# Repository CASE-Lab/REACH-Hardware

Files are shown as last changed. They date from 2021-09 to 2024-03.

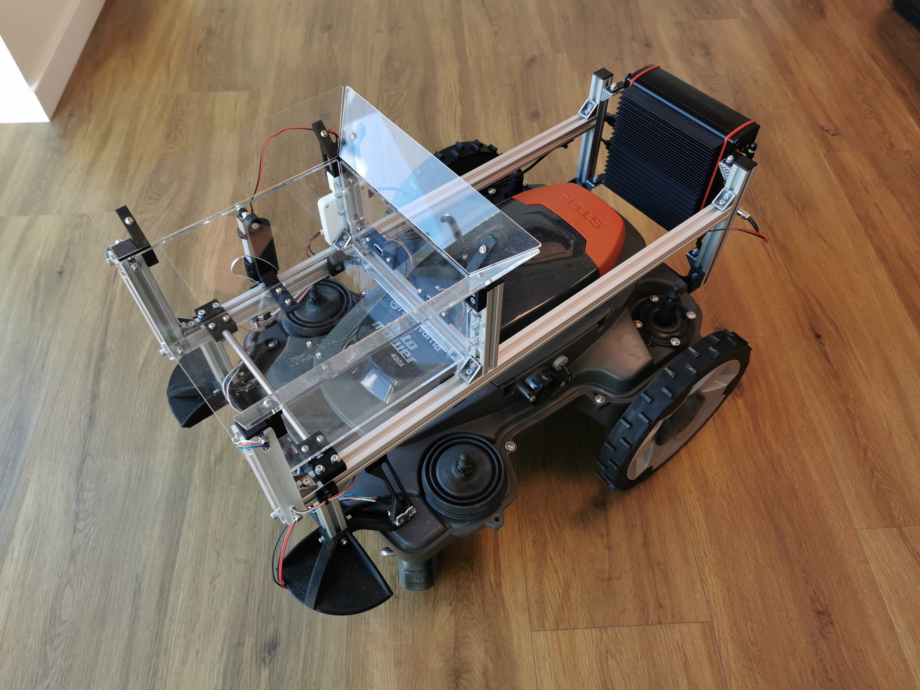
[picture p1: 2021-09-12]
Images/HRP/HRP_WithGarbageMoverAndREACH.jpg

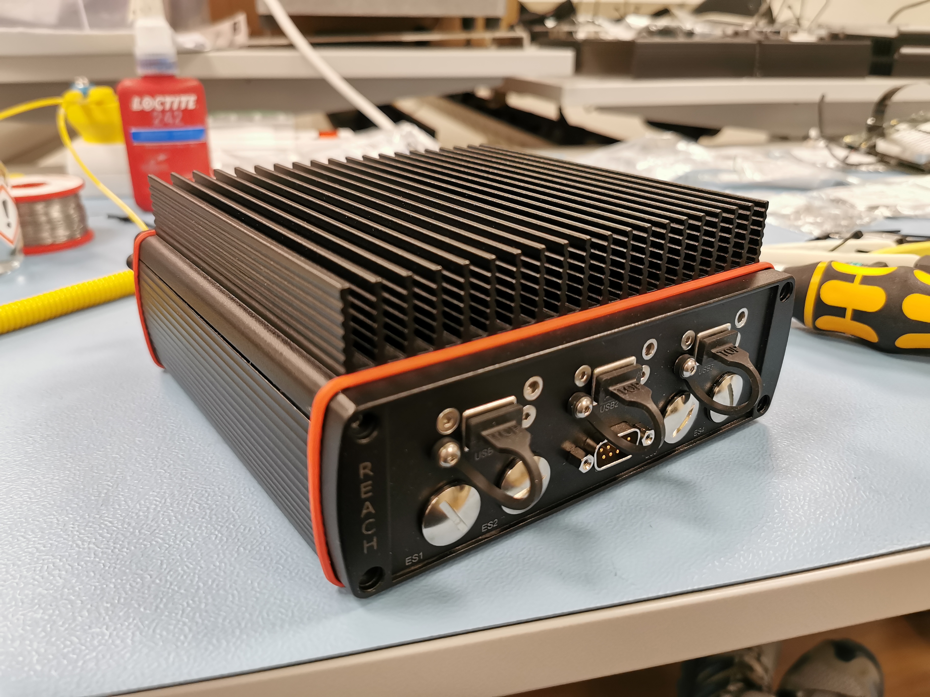
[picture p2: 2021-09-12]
Images/StandardVersion/TopStandardVersion.jpg

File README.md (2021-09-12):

# REACH-Hardware
REACH - Rugged Extensible Autonomous Control Hardware

## The REACH Unit
Is a fairly compact linux computer built upon the Nvidia Xavier NX developer kit. The main idea is to make the developer kit rugged and modular/extensible. 

### Fields of Interest
The unit is supposed to be used in the fields of robotics and automation if more robust and/or modular solution is needed. 

Example: A REACH unit is used in a research project with an autonomous jet ski. The rugged enclosure makes it ideal for the harsh environment. Because of it's modularity it also allows for future extensions to meet new needs that can arise. This version of the unit features two camera inputs and telemetry support.

Example: A REACH unit is used for controlling a Husqvarna Research Platform (HRP) (a modified robotic lawn mower for research purposes). It allows for enough computational power to easily run ROS2, while also allowing for a camera and USB devices to be connected in the future. This version of the unit is the standard version with one camera input and GPIO ports.

### Features
* Built upon an Nvidia NX developer kit
* Passively cooled
* Should attain an IP65 rating (untested)
* Allows for use of up to two Raspberry PI cameras over a distance of up to 10m using the HDMI to CSI adapter (adapter found in REACH-Extensions). (Number of supported cameras varies depending on the configuration)
* All standard connectors from the dev kit have been routed to the outside of the enclosure (1x Ethernet port, Wifi, 2-3x USB ports)
* Features up to 4 expansion cards which can add function such as CAN and RS232 support. Each card can be conencted to a standard M12 industrial connector located on the front panel.
* Depending on the configuration the unit features either 2 analogue and 5 digital GPIO pins or telemetry support.

[TOC]

## Getting Started

### Flashing with Nvidia SDK

* Currently requires Ubuntu 18.04 for Nvidia SDK Manager
* Can also be used on newer Ubuntu versions via Docker. [Instructions](https://docs.nvidia.com/sdk-manager/docker-containers/index.html)

### Booting from NVME SSD

* [Jetsonhacks Guide](https://www.jetsonhacks.com/2020/05/29/jetson-xavier-nx-run-from-ssd/)

### Stress testing

* Monitoring using jtop (requires pip for installation)

  ```sh
  # install
  sudo -H pip install -U jetson-stats
  # run
  sudo jtop
  ```

* Stress test GPU (and also CPU indirectly by running multiple instances of glmark2)

  ```sh
  # install
  sudo apt-get install -y glmark2
  # run
  glmark2
  ```

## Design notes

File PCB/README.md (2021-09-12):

# REACH-Hardware-PCB
This project uses only the KiCad ECAD program.

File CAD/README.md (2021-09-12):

REACH-Hardware-CAD
Contains the mechanical design files for the REACH unit. 

There are three assemblies of the unit that has been exported as .step. The others requires Autodesk Inventor 2022 or later.
- REACH_cam_version: Two camera inputs, two USB and GPIOs
- REACH_standard_version: One camera input, three USB and GPIOs
- REACH_waverunner_version: Two camera inputs, two USB and Telemetry support (used for the autonomousjet ski, MARV system)

The Inventor projets contains every part required to make the three exported versions, the unused parts are just hidden.

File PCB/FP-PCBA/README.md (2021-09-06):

# FP-PCBA

Front Panel PCB Assembly

* Breaks out USB 3.0 from Jetson development board to front panel
* Holds 4 modular expansion headers

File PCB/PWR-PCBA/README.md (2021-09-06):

# PWR-PCBA

Power distribution PCB assembly

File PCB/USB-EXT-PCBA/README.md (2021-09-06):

# USB-EXT-PCBA

USB interconnection to bring down upper USB connections to

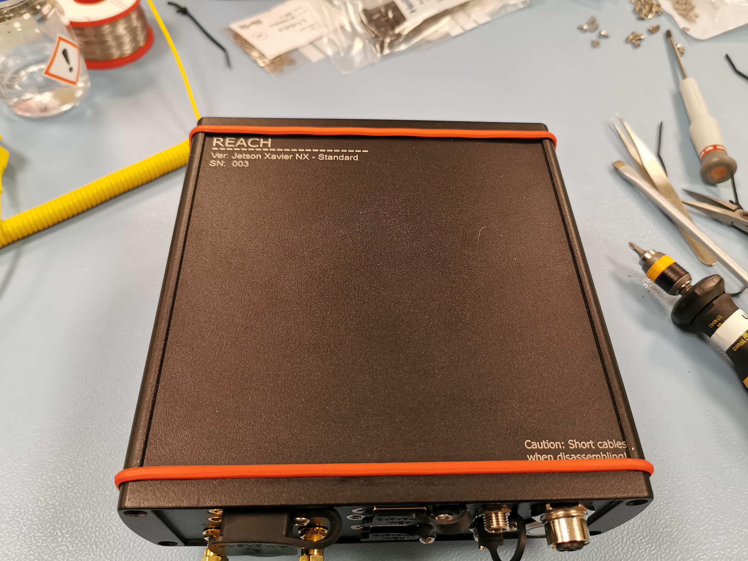
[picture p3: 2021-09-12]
Images/StandardVersion/BottomStandardVersion.jpg

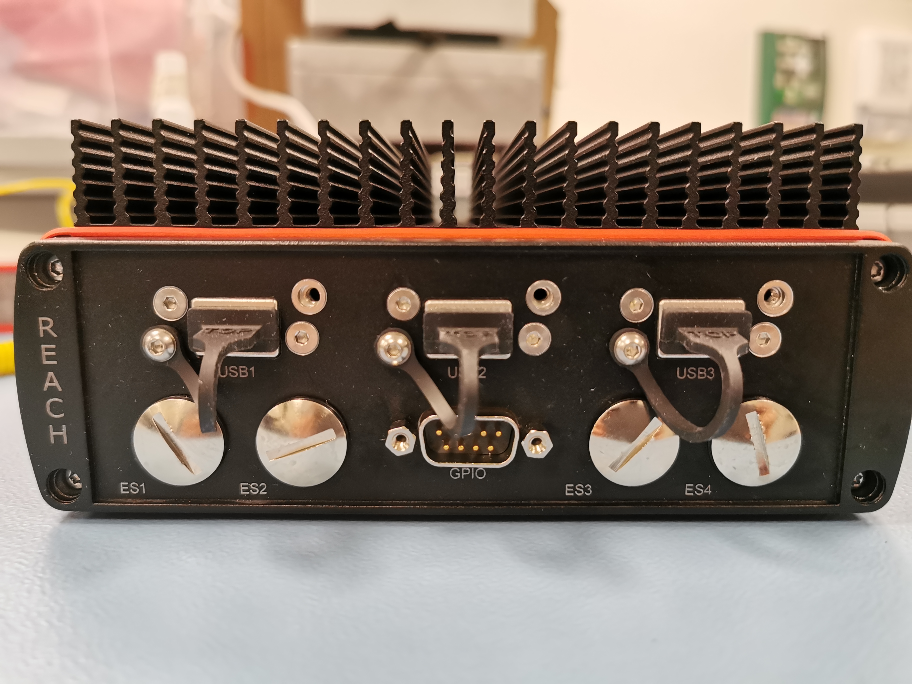
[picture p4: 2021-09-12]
Images/StandardVersion/FrontPanelStandardVersion.jpg

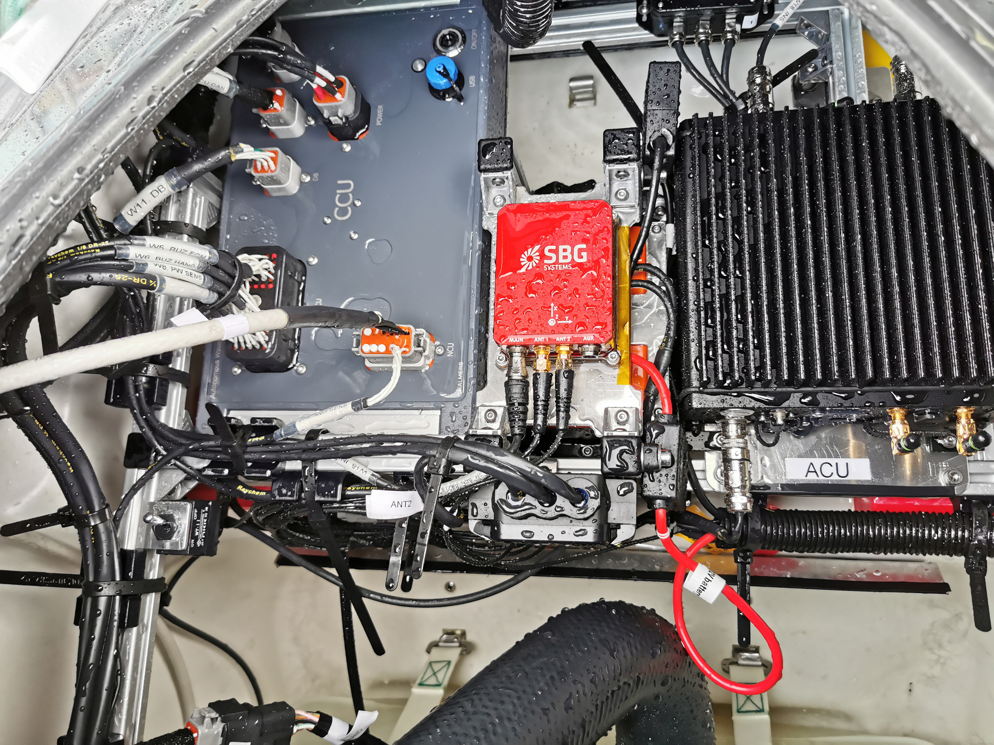
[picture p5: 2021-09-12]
Images/AutonomousJetSki/REACH_Unit_InJetSkiFrontCompartment.jpg

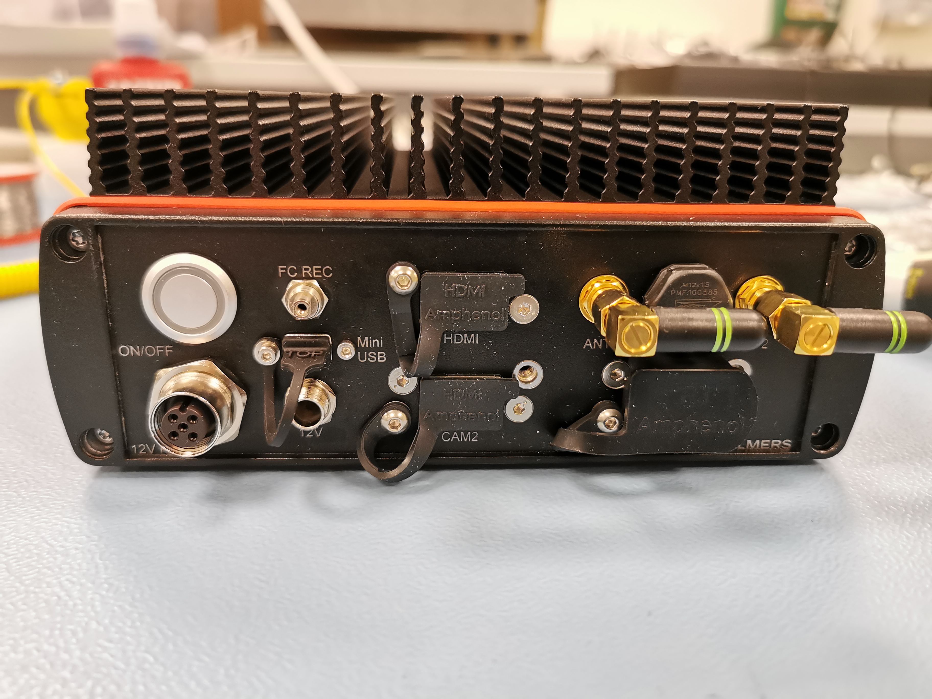
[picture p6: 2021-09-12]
Images/StandardVersion/BackPanelStandardVersion.jpg

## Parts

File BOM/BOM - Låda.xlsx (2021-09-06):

Komponent | Qty | Orderkod | Länk | Alt Länk | Tillverkare och MPN | Kommentar
Inbyggnadslåda
Låda - ABPH 1600-0150 K | 1 | 83658532 | https://se.lappgroup.com/produkter/webshop/kapslingar-och-skaap/elektronikkapslingar-i-metall/alubos-elegant-kapsling-av-aluminium-med-hoeg-skyddsklass-ip65/a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 |  | Bopla - ABPH 1600-0150 K
Gavel - ABD 1600 | 2 | 83654370 | https://se.lappgroup.com/produkter/webshop/kapslingar-och-skaap/elektronikkapslingar-i-metall/alubos-elegant-kapsling-av-aluminium-med-hoeg-skyddsklass-ip65/a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 |  | Bopla - ABD 1600
Packning - DI 1600-5002 elr DI 1600-3000 | 1 | 83654303 | https://se.lappgroup.com/produkter/webshop/kapslingar-och-skaap/elektronikkapslingar-i-metall/alubos-elegant-kapsling-av-aluminium-med-hoeg-skyddsklass-ip65/a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 |  | Bopla - DI 1600-5002 | Säljes i 10 pack
Fästen - AB-WL 3 | 1 | 150-79-678 | https://www.elfa.se/sv/vaeggfaeste-stal-svart-bopla-ab-wl/p/15079678 |  | Bopla - AB-WL 3
Bakre panel
On/Off Button - Staus LED
82-4551.1123 - 16mm rund | 1 | 301-27-185 | https://www.elfa.se/sv/tryckknapp-med-belysning-bla-16mm-12v-eao-82-4551-1123/p/30127185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 | https://se.rs-online.com/web/p/push-button-switches/8114053/?searchHistory=%7B%22enabled%22%3Atrue%7D | EAO - 82-4551.1123
Strömkontakter
Barrel - ST10U | 1 | 878-5257 | https://se.rs-online.com/web/p/dc-power-connectors/8785257/?searchHistory=%7B%22enabled%22%3Atrue%7D |  | Switchcraft - ST10U
M12 - 1424134 | 1 | 651-1424134 | https://www.mouser.se/ProductDetail/651-1424134 |  | Phoenix contact - 1424134
Force recovery switch
MB2011SD3G01-CA | 1 | 633-MB2011SD3G01-CA | https://www.mouser.se/ProductDetail/633-MB2011SD3G01-CA |  | NKK - MB2011SD3G01-CA
AT4042H - Boot for recovery switch | 0 |  |  |  | NKK - AT4042H
USB mini
MUSBR-B551-30 | 1 | MUSBR-B551-30-ND | https://www.digikey.se/product-detail/sv/amphenol-icc-commercial-products/MUSBR-B551-30/MUSBR-B551-30-ND/6137591 | https://se.farnell.com/amphenol-commercial-products/musbrb55130/t-t-usb-2-0-typ-mini-b-hona-ip67/dp/2708983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 | Amphenol - MUSBR-B551-30
HDMI kontakt (kamera och skärm utgång)
MHDR-A511-M0 | 2 | 523-MHDR-A511-M0 | https://www.mouser.se/ProductDetail/523-MHDR-A511-M0 |  | Amphenol - MHDR-A511-M0
Gore ventil
Ventil - PMF 100585 | 1 | 300-82-596 | https://www.elfa.se/sv/tryckutjaemningselement-m12-12-2mm-ip69k-polyamid-svart-gore-associates-gmbh-pmf-100585/p/30082596 |  | Gore - PMF 100585
Mutter M12 | 1 | 155-02-455 | https://www.elfa.se/sv/mutter-m12-gra-hummel-262-1200-50/p/15502455?mainId=30082596 |  | Hummel - 1.262.1200.50
Wifi
Antenn | 0 | 741-001-0012 | https://www.mouser.se/ProductDetail/741-001-0012 |  | Laird - 001-0012
Antenn liten | 2 | 960-GW260152 | https://www.mouser.se/ProductDetail/Taoglas/GW260152/?qs=WUa1z%2FNV9%252B3LPhGjmEzKfw%3D%3D |  | Taoglas - GW.26.0152
Koaxialkabel | 2 | 523-095-902-503-150 | https://www.mouser.se/ProductDetail/523-095-902-503-150/ |  | Amphenol - 095-902-503-150 | OSB uppdatera till Amphenol
RJ45 kontakt
MRJ5784M1 | 1 | 523-MRJ5784M1 | https://www.mouser.se/ProductDetail/523-MRJ5784M1 |  | Amphenol - MRJ5784M1
Dust covers
USB mini - MUSB2E151015BP | 1 | 523-MUSB2E151015BP | https://www.mouser.se/ProductDetail/523-MUSB2E151015BP | https://se.farnell.com/amphenol-icc-commercial-products/musb-2e151-015bp/dust-cover-mini-usb-conn-rubber/dp/2751481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 | Amphenol - MUSB2E151015BP
HDMI - MHDR2A11014BP | 2 | 523-MHDR2A11014BP | https://www.mouser.se/ProductDetail/523-MHDR2A11014BP | https://www.digikey.se/product-detail/en/MHDR2A11014BP/MHDR2A11014BP-ND/8572893?curr=usd | Amphenol - MHDR2A11014BP
RJ45 - MRJ-2586-20BP | 0 | 523-MRJ-2586-20BP | https://www.mouser.se/ProductDetail/523-MRJ-2586-20BP |  | Amphenol - MRJ-2586-20BP
RJ45 - MRJ258642BP | 1 | MRJ258642BP-ND | https://www.digikey.se/product-detail/en/MRJ258642BP/MRJ258642BP-ND/4889368?curr=usd | https://se.farnell.com/amphenol-commercial-products/mrj258642bp/dammlock-modul-r-kontakt-gummi/dp/2708972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 | Amphenol - MRJ258642BP
Nitmuttrar/Skruv
PD-CAP-3/8-0 | 4 | 650-PD-CAP-3/8-0 | https://www.mouser.se/ProductDetail/TE-Connectivity-Raychem/PD-CAP-3-8-0/?qs=tWoSwDyEbWQOoOS7Tg0daQ%3D%3D |  | TE Connectivity - PD-CAP-3/8-0
PSZROX-0315 | 0 | 623-5498 | https://se.rs-online.com/web/p/threaded-inserts/6235498/?searchHistory=%7B%22enabled%22%3Atrue%7D |  | POP - PSZROX-0315
M3X9.0 (1.5-1.5) RH-KB ST/ST A4 RIV-NUT | 4 | 206-7808 | https://se.rs-online.com/web/p/rivets/2067808 |  | RS PRO
ISO 4762 - M2 x 6ISO | 1
ISO 4762 - M2 x 8ISO | 1
ISO 10642 - M3x6 | 5
ISO 7380-1 - M3 x 6 | 2
ISO 7380-1 - M3 x 8 | 1
PCBS
Mini USB adapter | 1
HDMI adapter | 1
Camera adapter | 1
Främre panel
USB kontakter
MUSBR-3193-M0 | 3 (2) | 176-9048 | https://se.rs-online.com/web/p/usb-connectors/1769048/?searchHistory=%7B%22enabled%22%3Atrue%7D |  | Amphenol - MUSBR-3193-M0 | Antingen 3 USB och en HDMI för kamera, eller 4 USB
HDMI kontakt (kamera)
MHDR-A511-M0 | 0 (1) | 523-MHDR-A511-M0 | https://www.mouser.se/ProductDetail/523-MHDR-A511-M0 |  | Amphenol - MHDR-A511-M0 | Antingen 3 USB och en HDMI för kamera, eller 4 USB
Extension M12 PG9 kontakter (upp till 4 st)
CAN Bus - T4131012051-000, A-key, 5 pin | 1 | 134-5763 | https://se.rs-online.com/web/p/products/1345763/ |  | TE - T4131012051-000
M12 dust cap (invändig gänga) | - | 571-2823064-1 | https://www.mouser.se/ProductDetail/571-2823064-1 |  | TE - 2823064-1 | En per kontakt
Pluggar PG9 - Oring | - | 175-3751 | https://se.rs-online.com/web/p/cable-gland-plugs/1753751/?sra=pmpn |  | Alpha Wire - HPP9 BK080 | En per tomt hål, för oringen
Pluggar PG9 | - | 243-9191 | https://se.rs-online.com/web/p/cable-gland-plugs/2439191/?sra=pstk |  | Lapp - 52003390
Mutter till Plugg PG9 | - | 161-2979 | https://se.rs-online.com/web/p/cable-gland-locknuts/1612979/?searchHistory=%7B%22enabled%22%3Atrue%7D |  | SES Sterling - ?? | En per tomt hål
DSUB 9 Kontakt
MDBRE09PMAN0 | 1 | 523-MDBRE09PMAN0 | https://www.mouser.se/ProductDetail/523-MDBRE09PMAN0 |  | Amphenol - MDBRE09PMAN0
Standoff - 5207953-3 | 2 | 717-4559 | https://se.rs-online.com/web/p/d-sub-connector-accessories/7174559/?searchHistory=%7B%22enabled%22%3Atrue%7D |  | TE - 5207953-3
Dust covers
HDMI - MHDR2A11014BP | 0 (1) | 523-MHDR2A11014BP | https://www.mouser.se/ProductDetail/523-MHDR2A11014BP | https://www.digikey.se/product-detail/en/MHDR2A11014BP/MHDR2A11014BP-ND/8572893?curr=usd | Amphenol - MHDR2A11014BP | Antingen 3 USB och en HDMI för kamera, eller 4 USB
USB A - MUSB-2A111-024-BP | 3 (2) | 523-MUSB2A111024BP | https://www.mouser.se/ProductDetail/523-MUSB2A111024BP |  | Amphenol - MUSB-2A111-024-BP | Antingen 3 USB och en HDMI för kamera, eller 4 USB
DSUB 9 | 1
Nitmuttrar/Skruv
PD-CAP-3/8-0 | 6 | 650-PD-CAP-3/8-0 | https://www.mouser.se/ProductDetail/TE-Connectivity-Raychem/PD-CAP-3-8-0/?qs=tWoSwDyEbWQOoOS7Tg0daQ%3D%3D |  | TE Connectivity - PD-CAP-3/8-0
PSZROX-0315 | 0 | 623-5498 | https://se.rs-online.com/web/p/threaded-inserts/6235498/?searchHistory=%7B%22enabled%22%3Atrue%7D |  | POP - PSZROX-0315
M3X9.0 (1.5-1.5) RH-KB ST/ST A4 RIV-NUT | 6 | 206-7808 | https://se.rs-online.com/web/p/rivets/2067808 |  | RS PRO
ISO 10642 - M3x6 | 6
ISO 7380-1 - M3 x 8 | 3
D-sub standoff | 2 | 717-4559 | https://se.rs-online.com/web/p/d-sub-connector-accessories/7174559/ |  | TE Connectivity - 5207953-3
Hårdvara insida/övrigt
Jetson nano- ELLER Jetson NX dev kit
32 gb minneskort, alt även m2 ssd för NX |  |  | https://www.dustin.se/product/5011208877/ultra | https://www.dustin.se/product/5011146123/a2000
Wifi modul (följer med NX)
Modul | 0 | 607-8265.NGWMG.NV | https://www.mouser.se/ProductDetail/Intel/8265NGWMGNV?qs=sGAEpiMZZMu3sxpa5v1qrvoXwgKUd5RfZxSJYigdw1I= |  | Intel - 8265.NGWMG.NV
HDMI kabel och Kontakt
Adafruit 3550 - L böjd HDMI kontakt | 1 | 1528-2364-ND/485-3550 | https://www.digikey.se/product-detail/sv/adafruit-industries-llc/3550/1528-2364-ND/7623052 | https://www.mouser.se/ProductDetail/Adafruit/3550?qs=YCa%2FAAYMW01YtgwxLLaB3Q%3D%3D | Adafruit - 3550
Adafruit 3561 - Flatkabel - 20cm | 1 | 1528-2375-ND/485-3561 | https://www.digikey.se/product-detail/sv/adafruit-industries-llc/3561/1528-2375-ND/7623063 | https://www.mouser.se/ProductDetail/Adafruit/3561?qs=YCa%2FAAYMW0043V1Jh9FQbQ%3D%3D | Adafruit - 3561
Kamera flatkabel
Adafruit 1648 - 30cm | 2/(1) | 301-33-567 | https://www.elfa.se/sv/flexkabel-till-raspberry-pi-kamera-eller-display-adafruit-1648/p/30133567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 |  | Adafruit - 1648
Adafruit 1647 - 20cm | 0/(1) | 301-33-566 | https://www.elfa.se/sv/flexkabel-till-raspberry-pi-kamera-eller-display-adafruit-1647/p/30133566 |  | Adafruit - 1647
Boot (För HDMI/USB och RJ45)
MUSBR-AHD2-L41SK | 4 | 523-MUSBR-AHD2-L41SK | https://www.mouser.se/ProductDetail/523-MUSBR-AHD2-L41SK |  | Amphenol - MUSBR-AHD2-L41SK | För att alla vattentäta anslutningar skall kunna användas
Standoffs för kretskort montering
M2.5x7 - 970070154 | 4 | 184-3002 | https://se.rs-online.com/web/p/standoffs/1843002/ |  | Wurth - 970070154
M2.5x9 - 970090154 | 2 | 205-2899 | https://se.rs-online.com/web/p/standoffs/2052899 |  | Wurth - 970090154
M2.5x12 - 970120154 | 4 | 184-2719 | https://se.rs-online.com/web/p/standoffs/1842719/?searchHistory=%7B%22enabled%22%3Atrue%7D |  | Wurth - 970120154
M2.5x20 - 970200154 | 4 | 205-2901 | https://se.rs-online.com/web/p/standoffs/2052901/ |  | Wurth - 970200154
M2.5x5 - 971050154 | 4 | 184-2967 | https://se.rs-online.com/web/p/standoffs/1842967 |  | Wurth - 971050154
Skruv och Strips
Bricka M2.5 | 32
Bricka M3 | 1
ISO 4762 - M2.5 x 5ISO | 10
ISO 4762 - M2.5 x 6ISO | 8
ISO 4762 - M2.5 x 8ISO | 10
ISO 4762 - M3 x 8ISO | 1
Strips | 12
Tillbehör och verktyg för montering
Packningsfett för o-ringar Loctite 8104 | NA | 2457840 | https://www.tools.se/produkterSe/industri--och-byggkemikalier/smorj/smorjmedel-och-oljor/FETT-SILIKON-LMG-8104-75ML-SE-2457840-sv-SE |  | Loctite - 8104 | Går bra att ersätta med annat silikonbaserat packningsfett
Tillbehör och verktyg för montering
Thermal Pad SSD kylning | NA | 739-A14568-01 | https://eu.mouser.com/ProductDetail/Laird-Performance-Materials/A14568-01/?qs=3IuyYncJTQFbQ7Np1cGCMQ%3D%3D |  | Laird - A14568-01 | Kolla värmeutveckling och se om det behövs först (inte billig men stor bit så räcker till många SSD:er)
Thermal Paste | NA | 174-4911 | https://se.rs-online.com/web/p/thermal-grease/1744911/?searchHistory=%7B%22enabled%22%3Afalse%7D |  | Electrotube - ERHTCP02S
Thermal Pad 0.5mm | NA | 567-PL-05-3-1016-H | https://www.mouser.se/ProductDetail/Wakefield-Vette/PL-05-3-1016-H/ |  | Wakefield-Vette - PL-05-3-1016-H
Thermal Pad 1.0mm | NA | 567-PL-1-3-1016-H | https://www.mouser.se/ProductDetail/Wakefield-Vette/PL-1-3-1016-H/ |  | Wakefield-Vette - PL-1-3-1016-H
Mekaniska delar
Fixture Plate | 1 | Fräst
Cable Fastener | 1 | Fräst
Module Bracket | 2 | 3D print
Front Panel | 1 | Fräst
Back Panel | 1 | Fräst
Thermal Conductivity Block | 1 | Fräst
PWR_PCBA_HeatSink | 1 | Fräst
Connector Stop | 1 | 3D print

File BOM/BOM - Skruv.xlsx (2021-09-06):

Skruv | Antal | Kostnad | Summa | Länk | Total kostnad | 150.88 kr
ISO 4762 - M2 x 6 | 2 | 1.08 kr | 2.16 kr | https://fastpro.se/produkter/insexskruv/mc6s-din-912-a4-syrafast-insexskruv
ISO 4762 - M2.5 x 5 | 10 | 0.61 kr | 6.10 kr
ISO 4762 - M2.5 x 6 | 4 | 0.59 kr | 2.36 kr
ISO 4762 - M2.5 x 8 | 10 | 0.62 kr | 6.20 kr
ISO 4762 - M2.5 x 16 | 4 | 0.76 kr | 3.04 kr
ISO 4762 - M3 x 4 | 8 | 0.70 kr | 5.60 kr
ISO 10642 - M3x6 | 11 | 0.24 kr | 2.64 kr | https://fastpro.se/produkter/insexskruv/mf6s-din-7991-a4-syrafast-insexskruv-forsankt
ISO 7380-1 - M3 x 6 | 4 | 0.41 kr | 1.64 kr | https://fastpro.se/produkter/insexskruv/mk6s-iso-7380-a4-syrafast-insexskruv-kullrig
ISO 7380-1 - M3 x 8 | 3 | 0.44 kr | 1.32 kr
Distanser
M2.5x7mm_Standoff_ 970070151 | 4 | 5.00 kr | 20.00 kr | https://se.rs-online.com/web/p/standoffs/1768429/
M2.5x9mm_Standoff_ 970090144 | 2 | 6.50 kr | 13.00 kr | https://se.rs-online.com/web/p/standoffs/1842655/
M2.5x12mm_Standoff_ 970120144 | 4 | 8.00 kr | 32.00 kr | https://www.mouser.se/ProductDetail/Wurth-Elektronik/970120144
M2.5x20mm_Standoff_ 970200144 | 4 | 8.00 kr | 32.00 kr | https://www.mouser.se/ProductDetail/Wurth-Elektronik/970200144
WE_960060021 | 4 | 1.50 kr | 6.00 kr | https://se.rs-online.com/web/p/round-spacers/1842529/
Brickor
DIN 125 - A 2.8 | 18 | 0.09 kr | 1.62 kr | https://fastpro.se/produkter/bricka/rb-din-125-a4-syrafast-rundbricka
Nitmuttrar
pop_PSZROX-0315 | 8 | 1.40 kr | 11.20 kr | https://se.rs-online.com/web/p/threaded-inserts/6235498/
DSUB distanser
5207953-3 | 2 | 2.00 kr | 4.00 kr | https://se.rs-online.com/web/p/d-sub-connector-accessories/7174559/

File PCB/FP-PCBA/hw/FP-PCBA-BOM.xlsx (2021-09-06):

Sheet: Merged BOM
Project Unicorn: FP-PCBA BOM |  | Chalmers University of Technology
REV: 2 |  | REV Date: 2020-11-12
Reference | Qty | Value | Distributor | Distributor PN | MPN | Manufacturer | DNP | Comments
Non PCB Items
Kicad CSV Imported Items
C4 C5 C6 C3 | 4 | 0.1uF | Mouser | 581-06033C104KAT4A | 06033C104KAT4A | AVX
C7 C2 C1 | 3 | 1uF | Mouser | 80-C0603C105K4RLR | C0603C105K4RAC7411 | KEMET
H1 H2 H3 H4 | 4 | M2.5 |  |  |  |  | DNP
H5 H6 | 2 | M2.5 |  |  |  |  | DNP
H7 H8 | 2 | 2.2mm |  |  |  |  | DNP
IC1 | 1 | CP2108-B03-GM | Mouser | 634-CP2108-B02-GMR | CP2108-B02-GMR | Silicon Labs |  | Change to B03 variant (currently not in stock)
J1 | 1 | Conn_01x04 | Mouser | 538-505568-0471 | 505568-0471 | Molex | DNP | Only populate if used
J10 J11 | 2 | USB3_A | Mouser | 523-GSB316441CEU | GSB316441CEU | Amphenol
J12 | 1 | 2x USB 3.0 Header | Mouser | 200-TW1011TD250080 | TW-10-11-T-D-250-080 | Samtec |  | Pin numbering changed to match footprint
J4 J3 J2 | 3 | MUSBR-3193-M0 | Mouser | 523-MUSBR-3193-M0 | MUSBR-3193-M0 | Amphenol
J9 | 1 | ZF5S-30-01-T-WT | Mouser | 200-ZF5S3003TWTTR | ZF5S-30-03-T-WT | Samtec |  | To FP-PCBA
MOD4 MOD3 MOD2 MOD1 | 4 | Conn_02x07_Counter_Clockwise | Mouser | 200-HLE1072FDVBEAKTR | HLE-107-02-F-DV-BE-A-K-TR | Samtec |  | Check datasheet for compatible variants
R1 | 1 | 100k | CASE
TP3 TP2 TP1 TP5 TP4 TP6 | 6 | TestPoint |  |  |  |  | DNP
0 | 0 | 0 | 0 | 0 | 0 | 0 | 0 | 0
0 | 0 | 0 | 0 | 0 | 0 | 0 | 0 | 0
0 | 0 | 0 | 0 | 0 | 0 | 0 | 0 | 0
0 | 0 | 0 | 0 | 0 | 0 | 0 | 0 | 0
0 | 0 | 0 | 0 | 0 | 0 | 0 | 0 | 0
0 | 0 | 0 | 0 | 0 | 0 | 0 | 0 | 0
0 | 0 | 0 | 0 | 0 | 0 | 0 | 0 | 0
0 | 0 | 0 | 0 | 0 | 0 | 0 | 0 | 0
0 | 0 | 0 | 0 | 0 | 0 | 0 | 0 | 0
0 | 0 | 0 | 0 | 0 | 0 | 0 | 0 | 0
0 | 0 | 0 | 0 | 0 | 0 | 0 | 0 | 0
0 | 0 | 0 | 0 | 0 | 0 | 0 | 0 | 0
0 | 0 | 0 | 0 | 0 | 0 | 0 | 0 | 0
0 | 0 | 0 | 0 | 0 | 0 | 0 | 0 | 0
0 | 0 | 0 | 0 | 0 | 0 | 0 | 0 | 0
0 | 0 | 0 | 0 | 0 | 0 | 0 | 0 | 0
0 | 0 | 0 | 0 | 0 | 0 | 0 | 0 | 0
0 | 0 | 0 | 0 | 0 | 0 | 0 | 0 | 0
0 | 0 | 0 | 0 | 0 | 0 | 0 | 0 | 0
0 | 0 | 0 | 0 | 0 | 0 | 0 | 0 | 0
0 | 0 | 0 | 0 | 0 | 0 | 0 | 0 | 0
0 | 0 | 0 | 0 | 0 | 0 | 0 | 0 | 0
0 | 0 | 0 | 0 | 0 | 0 | 0 | 0 | 0
0 | 0 | 0 | 0 | 0 | 0 | 0 | 0 | 0
0 | 0 | 0 | 0 | 0 | 0 | 0 | 0 | 0
0 | 0 | 0 | 0 | 0 | 0 | 0 | 0 | 0
0 | 0 | 0 | 0 | 0 | 0 | 0 | 0 | 0
0 | 0 | 0 | 0 | 0 | 0 | 0 | 0 | 0
0 | 0 | 0 | 0 | 0 | 0 | 0 | 0 | 0
0 | 0 | 0 | 0 | 0 | 0 | 0 | 0 | 0
0 | 0 | 0 | 0 | 0 | 0 | 0 | 0 | 0
0 | 0 | 0 | 0 | 0 | 0 | 0 | 0 | 0
0 | 0 | 0 | 0 | 0 | 0 | 0 | 0 | 0
0 | 0 | 0 | 0 | 0 | 0 | 0 | 0 | 0
0 | 0 | 0 | 0 | 0 | 0 | 0 | 0 | 0
0 | 0 | 0 | 0 | 0 | 0 | 0 | 0 | 0
0 | 0 | 0 | 0 | 0 | 0 | 0 | 0 | 0
0 | 0 | 0 | 0 | 0 | 0 | 0 | 0 | 0
0 | 0 | 0 | 0 | 0 | 0 | 0 | 0 | 0
0 | 0 | 0 | 0 | 0 | 0 | 0 | 0 | 0
0 | 0 | 0 | 0 | 0 | 0 | 0 | 0 | 0
0 | 0 | 0 | 0 | 0 | 0 | 0 | 0 | 0
0 | 0 | 0 | 0 | 0 | 0 | 0 | 0 | 0
0 | 0 | 0 | 0 | 0 | 0 | 0 | 0 | 0
0 | 0 | 0 | 0 | 0 | 0 | 0 | 0 | 0
0 | 0 | 0 | 0 | 0 | 0 | 0 | 0 | 0
0 | 0 | 0 | 0 | 0 | 0 | 0 | 0 | 0
0 | 0 | 0 | 0 | 0 | 0 | 0 | 0 | 0
0 | 0 | 0 | 0 | 0 | 0 | 0 | 0 | 0
0 | 0 | 0 | 0 | 0 | 0 | 0 | 0 | 0
0 | 0 | 0 | 0 | 0 | 0 | 0 | 0 | 0
0 | 0 | 0 | 0 | 0 | 0 | 0 | 0 | 0
0 | 0 | 0 | 0 | 0 | 0 | 0 | 0 | 0
0 | 0 | 0 | 0 | 0 | 0 | 0 | 0 | 0
0 | 0 | 0 | 0 | 0 | 0 | 0 | 0 | 0
0 | 0 | 0 | 0 | 0 | 0 | 0 | 0 | 0
0 | 0 | 0 | 0 | 0 | 0 | 0 | 0 | 0
0 | 0 | 0 | 0 | 0 | 0 | 0 | 0 | 0
0 | 0 | 0 | 0 | 0 | 0 | 0 | 0 | 0
0 | 0 | 0 | 0 | 0 | 0 | 0 | 0 | 0
0 | 0 | 0 | 0 | 0 | 0 | 0 | 0 | 0
0 | 0 | 0 | 0 | 0 | 0 | 0 | 0 | 0
0 | 0 | 0 | 0 | 0 | 0 | 0 | 0 | 0
0 | 0 | 0 | 0 | 0 | 0 | 0 | 0 | 0
0 | 0 | 0 | 0 | 0 | 0 | 0 | 0 | 0
0 | 0 | 0 | 0 | 0 | 0 | 0 | 0 | 0
0 | 0 | 0 | 0 | 0 | 0 | 0 | 0 | 0
0 | 0 | 0 | 0 | 0 | 0 | 0 | 0 | 0
0 | 0 | 0 | 0 | 0 | 0 | 0 | 0 | 0
0 | 0 | 0 | 0 | 0 | 0 | 0 | 0 | 0
0 | 0 | 0 | 0 | 0 | 0 | 0 | 0 | 0
0 | 0 | 0 | 0 | 0 | 0 | 0 | 0 | 0
0 | 0 | 0 | 0 | 0 | 0 | 0 | 0 | 0
0 | 0 | 0 | 0 | 0 | 0 | 0 | 0 | 0
0 | 0 | 0 | 0 | 0 | 0 | 0 | 0 | 0
0 | 0 | 0 | 0 | 0 | 0 | 0 | 0 | 0
0 | 0 | 0 | 0 | 0 | 0 | 0 | 0 | 0
0 | 0 | 0 | 0 | 0 | 0 | 0 | 0 | 0
0 | 0 | 0 | 0 | 0 | 0 | 0 | 0 | 0
0 | 0 | 0 | 0 | 0 | 0 | 0 | 0 | 0
0 | 0 | 0 | 0 | 0 | 0 | 0 | 0 | 0
0 | 0 | 0 | 0 | 0 | 0 | 0 | 0 | 0
0 | 0 | 0 | 0 | 0 | 0 | 0 | 0 | 0
0 | 0 | 0 | 0 | 0 | 0 | 0 | 0 | 0
0 | 0 | 0 | 0 | 0 | 0 | 0 | 0 | 0
0 | 0 | 0 | 0 | 0 | 0 | 0 | 0 | 0
0 | 0 | 0 | 0 | 0 | 0 | 0 | 0 | 0
0 | 0 | 0 | 0 | 0 | 0 | 0 | 0 | 0
0 | 0 | 0 | 0 | 0 | 0 | 0 | 0 | 0
0 | 0 | 0 | 0 | 0 | 0 | 0 | 0 | 0
0 | 0 | 0 | 0 | 0 | 0 | 0 | 0 | 0
0 | 0 | 0 | 0 | 0 | 0 | 0 | 0 | 0
0 | 0 | 0 | 0 | 0 | 0 | 0 | 0 | 0
0 | 0 | 0 | 0 | 0 | 0 | 0 | 0 | 0
0 | 0 | 0 | 0 | 0 | 0 | 0 | 0 | 0
0 | 0 | 0 | 0 | 0 | 0 | 0 | 0 | 0
0 | 0 | 0 | 0 | 0 | 0 | 0 | 0 | 0
0 | 0 | 0 | 0 | 0 | 0 | 0 | 0 | 0
0 | 0 | 0 | 0 | 0 | 0 | 0 | 0 | 0
0 | 0 | 0 | 0 | 0 | 0 | 0 | 0 | 0
0 | 0 | 0 | 0 | 0 | 0 | 0 | 0 | 0
0 | 0 | 0 | 0 | 0 | 0 | 0 | 0 | 0
0 | 0 | 0 | 0 | 0 | 0 | 0 | 0 | 0
0 | 0 | 0 | 0 | 0 | 0 | 0 | 0 | 0
0 | 0 | 0 | 0 | 0 | 0 | 0 | 0 | 0
0 | 0 | 0 | 0 | 0 | 0 | 0 | 0 | 0
0 | 0 | 0 | 0 | 0 | 0 | 0 | 0 | 0
0 | 0 | 0 | 0 | 0 | 0 | 0 | 0 | 0
0 | 0 | 0 | 0 | 0 | 0 | 0 | 0 | 0
0 | 0 | 0 | 0 | 0 | 0 | 0 | 0 | 0
0 | 0 | 0 | 0 | 0 | 0 | 0 | 0 | 0
0 | 0 | 0 | 0 | 0 | 0 | 0 | 0 | 0
0 | 0 | 0 | 0 | 0 | 0 | 0 | 0 | 0
0 | 0 | 0 | 0 | 0 | 0 | 0 | 0 | 0
0 | 0 | 0 | 0 | 0 | 0 | 0 | 0 | 0
0 | 0 | 0 | 0 | 0 | 0 | 0 | 0 | 0
0 | 0 | 0 | 0 | 0 | 0 | 0 | 0 | 0
0 | 0 | 0 | 0 | 0 | 0 | 0 | 0 | 0
0 | 0 | 0 | 0 | 0 | 0 | 0 | 0 | 0
0 | 0 | 0 | 0 | 0 | 0 | 0 | 0 | 0
0 | 0 | 0 | 0 | 0 | 0 | 0 | 0 | 0
0 | 0 | 0 | 0 | 0 | 0 | 0 | 0 | 0
0 | 0 | 0 | 0 | 0 | 0 | 0 | 0 | 0
0 | 0 | 0 | 0 | 0 | 0 | 0 | 0 | 0
0 | 0 | 0 | 0 | 0 | 0 | 0 | 0 | 0
0 | 0 | 0 | 0 | 0 | 0 | 0 | 0 | 0
0 | 0 | 0 | 0 | 0 | 0 | 0 | 0 | 0
0 | 0 | 0 | 0 | 0 | 0 | 0 | 0 | 0
0 | 0 | 0 | 0 | 0 | 0 | 0 | 0 | 0
0 | 0 | 0 | 0 | 0 | 0 | 0 | 0 | 0
0 | 0 | 0 | 0 | 0 | 0 | 0 | 0 | 0
0 | 0 | 0 | 0 | 0 | 0 | 0 | 0 | 0
0 | 0 | 0 | 0 | 0 | 0 | 0 | 0 | 0
0 | 0 | 0 | 0 | 0 | 0 | 0 | 0 | 0
0 | 0 | 0 | 0 | 0 | 0 | 0 | 0 | 0
0 | 0 | 0 | 0 | 0 | 0 | 0 | 0 | 0
0 | 0 | 0 | 0 | 0 | 0 | 0 | 0 | 0
0 | 0 | 0 | 0 | 0 | 0 | 0 | 0 | 0
0 | 0 | 0 | 0 | 0 | 0 | 0 | 0 | 0
0 | 0 | 0 | 0 | 0 | 0 | 0 | 0 | 0
0 | 0 | 0 | 0 | 0 | 0 | 0 | 0 | 0
0 | 0 | 0 | 0 | 0 | 0 | 0 | 0 | 0
0 | 0 | 0 | 0 | 0 | 0 | 0 | 0 | 0
0 | 0 | 0 | 0 | 0 | 0 | 0 | 0 | 0
0 | 0 | 0 | 0 | 0 | 0 | 0 | 0 | 0
0 | 0 | 0 | 0 | 0 | 0 | 0 | 0 | 0

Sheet: csv-import
Reference | Quantity | Value | Footprint | Datasheet | DNP | Comments | Distributor | Distributor PN | MPN | Manufacturer
C4 C5 C6 C3 | 4 | 0.1uF | Capacitor_SMD:C_0603_1608Metric | ~ |  |  | Mouser | 581-06033C104KAT4A | 06033C104KAT4A | AVX
C7 C2 C1 | 3 | 1uF | Capacitor_SMD:C_0603_1608Metric | ~ |  |  | Mouser | 80-C0603C105K4RLR | C0603C105K4RAC7411 | KEMET
H1 H2 H3 H4 | 4 | M2.5 | MountingHole:MountingHole_2.7mm_M2.5_Pad_Via | ~ | DNP
H5 H6 | 2 | M2.5 | local:Slotted_2mm_M2.5_Vias | ~ | DNP
H7 H8 | 2 | 2.2mm | MountingHole:MountingHole_2.2mm_M2_Pad | ~ | DNP
IC1 | 1 | CP2108-B03-GM | local:CP2108-B03-GM | https://www.silabs.com/documents/public/data-sheets/cp2108-datasheet.pdf |  | Change to B03 variant (currently not in stock) | Mouser | 634-CP2108-B02-GMR | CP2108-B02-GMR | Silicon Labs
J1 | 1 | Conn_01x04 | local:Molex_Micro_Lock_1x4_Vertical_5055680471 | https://datasheet.octopart.com/5055680471-Molex-datasheet-148189002.pdf | DNP | Only populate if used | Mouser | 538-505568-0471 | 505568-0471 | Molex
J10 J11 | 2 | USB3_A | local:USB3_A_Plug_AMPHENOL_GSB316441CEU | ~ |  |  | Mouser | 523-GSB316441CEU | GSB316441CEU | Amphenol
J12 | 1 | 2x USB 3.0 Header | Connector_PinHeader_2.00mm:PinHeader_2x10_P2.00mm_Vertical | https://www.intel.com/content/dam/www/public/us/en/documents/technical-specifications/usb3-internal-connector-cable-specification.pdf |  | Pin numbering changed to match footprint | Mouser | 200-TW1011TD250080 | TW-10-11-T-D-250-080 | Samtec
J4 J3 J2 | 3 | MUSBR-3193-M0 | local:MUSBR3193M0 | https://eu.mouser.com/datasheet/2/18/amphenol_06232017_MUSBR-3193-1156662.pdf |  |  | Mouser | 523-MUSBR-3193-M0 | MUSBR-3193-M0 | Amphenol
J9 | 1 | ZF5S-30-01-T-WT | local:ZF5S-30-03-T-WT | http://suddendocs.samtec.com/productspecs/zf5s.pdf |  | To FP-PCBA | Mouser | 200-ZF5S3003TWTTR | ZF5S-30-03-T-WT | Samtec
MOD4 MOD3 MOD2 MOD1 | 4 | Conn_02x07_Counter_Clockwise | local:Samtec_HLE-107-02-xxx-DV-BE-A_2x07_P2.54mm_Horizontal | https://eu.mouser.com/datasheet/2/527/hle-1370182.pdf |  | Check datasheet for compatible variants | Mouser | 200-HLE1072FDVBEAKTR | HLE-107-02-F-DV-BE-A-K-TR | Samtec
R1 | 1 | 100k | Resistor_SMD:R_0603_1608Metric | ~ |  |  | CASE
TP3 TP2 TP1 TP5 TP4 TP6 | 6 | TestPoint | TestPoint:TestPoint_THTPad_D1.0mm_Drill0.5mm | ~ | DNP

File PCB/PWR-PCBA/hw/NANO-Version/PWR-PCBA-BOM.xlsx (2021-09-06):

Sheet: Merged BOM
Project Unicorn: PWR-PCBA BOM |  | Chalmers University of Technology
REV: 2 |  | REV Date: 2020-07-22
Reference | Qty | Value | Distributor | Distributor PN | MPN | Manufacturer | DNP | Comments
Non PCB Items
J1-CABLE | 1 | NanoFit 02x02 cable | Mouser | 538-105308-1204 | 1053081204 | Molex
Nano fit pre-crimped receptable | 2 | 300 mm double ended | Mouser | 538-79758-2140 | 79758-2140 | Molex |  | Buy terminals instead if crimp tool is accessible
J2-CABLE | 1 | MicroLock 02x04 cable | RS | 186-5275 | 505432-0801 | Molex
J4-CABLE | 1 | MicroLock 01x09 cable | Mouser | 538-204532-0901 | 2045320901 | Molex
MicroLock crimp receptable | 17 | Tin plated receptable | RS | 161-5947 | 505431-1000 | Molex |  | Buy crimped leads if no crimp tools is accesible
J5-CABLE | 1 | 30 pin samtec FFC 2" | RS | 197-6642 | FJH-30-D-02.00-4 | Samtec |  | Same side (D)
Kicad CSV Imported Items
C12 C13 | 2 | 220uF 25V | Elfa | 301-51-797 | ESE227M025AG3AA | KEMET
C14 C15 | 2 | 10uF >17 V X7R | RS | 184-3756 | TMK212BBJ106MG-T | Taiyo Yuden
C16 C17 | 2 | 22uF >6V X7R | RS | 691-1177 | C0805C226M9PACTU | Kemet
C2 C6 C1 C7 C8 C3 C10 C18 C23 | 9 | 0.1uF
C4 C5 C20 C25 | 4 | 1uF
C9 C19 C24 | 3 | ? |  |  |  |  | DNP
D1 | 1 | D_TVS | Mouser | 576-TPSMB20CA | TPSMB20CA | Littlefuse
D13 | 1 | LED GREEN
D2 | 1 | 12V | CASE |  | MMSZ5242B-G3-08 | Vishay
D3 D5 D4 | 3 | 5.1V | CASE |  | MMSZ5232B-7-F | Diodes Inc.
D6 | 1 | ESDA6V1-5SC6 | RS | 250-066 | ESDA6V1-5SC6 | ST
D7 D9 D11 | 3 | LED RED
D8 D10 D12 | 3 | D_Schottky | Mouser | 621-1N5819HW-F | 1N5819HW | Diodes Incorporated
H1 H3 H2 H4 | 4 | MountingHole_Pad
J1 | 1 | NanoFit 02x02 | Mouser | 538-105310-1204 | 105310-1204 | Molex
J2 | 1 | Micro Lock 02x04 | RS | 186-5193 | 5054330871 | Molex |  | Connetor for power on/off and LED indication
J3 | 1 | ZF5S-30-03-T-WT | Mouser | 200-ZF5S3003TWTTR | ZF5S-30-03-T-WT-TR | Samtec |  | To FP-PCBA
J4 | 1 | Micro Lock 01x09 | Elfa | 301-76-000 | 205957-0971 | Molex
J5 | 1 | Conn_02x20_Odd_Even | Mouser | 200-HLE12002FDVBEA | HLE-120-02-F-DV-BE-A | Samtec
Q1 | 1 | DMP3013SFV | Mouser | 621-DMP3013SFV-7 | DMP3013SFV-7 | Diodes Incorporated
Q2 Q4 Q5 Q3 Q6 Q7 | 6 | BSS138
R11 R23 | 2 | 1.6M
R13 R17 R15 | 3 | 27k
R2 | 1 | 1M
R22 R21 R20 R19 R18 | 5 | 160
R25 | 1 | 18k
R26 R30 | 2 | 39k
R27 | 1 | 2k
R28 | 1 | 270k
R29 | 1 | 30k
R31 | 1 | 1.2k
R32 | 1 | 4.3k
R33 | 1 | 10k
R34 | 1 | 1.1k
R35 | 1 | 270
R45 R38 R39 R42 R43 | 5 | 1k
R5 R3 R12 R4 R1 R10 R9 R16 R14 R6 R44 R24 R36 R37 R40 R41 | 16 | 100k
R7 | 1 | 0
R8 | 1 | ? |  |  |  |  | DNP
SW1 SW2 | 2 | SW_Push | CASE |  | KMR621NGLFS | C&K Components
TP1 TP2 TP3 TP4 TP21 TP20 TP19 TP18 TP17 TP16 TP15 TP14 TP13 TP12 TP11 TP10 TP9 TP8 TP7 TP6 TP5 TP22 TP23 TP24 | 24 | TestPoint
U1 | 1 | MCP23017_ML | RS | 687-8773 | MCP23017-E/ML | Microchip
U2 | 1 | LTC2955xDDB-1 | RS | 884-6927 | LTC2955IDDB-1#TRMPBF | LT
U3 | 1 | ADS1015BQDGSRQ1 | Mouser | 595-ADS1015BQDGSRQ1 | ADS1015BQDGSRQ1 | TI
U4 | 1 | TPS25940x-Q1 | Mouser | 595-TPS25940LQRVCRQ1 | TPS25940LQRVCRQ1 | TI |  | Latching and automotive variant
U6 U7 | 2 | TPS2595xx | Mouser | 595-TPS259570DSGR | TPS259570DSGR | TI
0 | 0 | 0 | 0 | 0 | 0 | 0 | 0 | 0
0 | 0 | 0 | 0 | 0 | 0 | 0 | 0 | 0
0 | 0 | 0 | 0 | 0 | 0 | 0 | 0 | 0
0 | 0 | 0 | 0 | 0 | 0 | 0 | 0 | 0
0 | 0 | 0 | 0 | 0 | 0 | 0 | 0 | 0
0 | 0 | 0 | 0 | 0 | 0 | 0 | 0 | 0
0 | 0 | 0 | 0 | 0 | 0 | 0 | 0 | 0
0 | 0 | 0 | 0 | 0 | 0 | 0 | 0 | 0
0 | 0 | 0 | 0 | 0 | 0 | 0 | 0 | 0
0 | 0 | 0 | 0 | 0 | 0 | 0 | 0 | 0
0 | 0 | 0 | 0 | 0 | 0 | 0 | 0 | 0
0 | 0 | 0 | 0 | 0 | 0 | 0 | 0 | 0
0 | 0 | 0 | 0 | 0 | 0 | 0 | 0 | 0
0 | 0 | 0 | 0 | 0 | 0 | 0 | 0 | 0
0 | 0 | 0 | 0 | 0 | 0 | 0 | 0 | 0
0 | 0 | 0 | 0 | 0 | 0 | 0 | 0 | 0
0 | 0 | 0 | 0 | 0 | 0 | 0 | 0 | 0
0 | 0 | 0 | 0 | 0 | 0 | 0 | 0 | 0
0 | 0 | 0 | 0 | 0 | 0 | 0 | 0 | 0
0 | 0 | 0 | 0 | 0 | 0 | 0 | 0 | 0
0 | 0 | 0 | 0 | 0 | 0 | 0 | 0 | 0
0 | 0 | 0 | 0 | 0 | 0 | 0 | 0 | 0
0 | 0 | 0 | 0 | 0 | 0 | 0 | 0 | 0
0 | 0 | 0 | 0 | 0 | 0 | 0 | 0 | 0
0 | 0 | 0 | 0 | 0 | 0 | 0 | 0 | 0
0 | 0 | 0 | 0 | 0 | 0 | 0 | 0 | 0
0 | 0 | 0 | 0 | 0 | 0 | 0 | 0 | 0
0 | 0 | 0 | 0 | 0 | 0 | 0 | 0 | 0
0 | 0 | 0 | 0 | 0 | 0 | 0 | 0 | 0
0 | 0 | 0 | 0 | 0 | 0 | 0 | 0 | 0
0 | 0 | 0 | 0 | 0 | 0 | 0 | 0 | 0
0 | 0 | 0 | 0 | 0 | 0 | 0 | 0 | 0
0 | 0 | 0 | 0 | 0 | 0 | 0 | 0 | 0
0 | 0 | 0 | 0 | 0 | 0 | 0 | 0 | 0
0 | 0 | 0 | 0 | 0 | 0 | 0 | 0 | 0
0 | 0 | 0 | 0 | 0 | 0 | 0 | 0 | 0
0 | 0 | 0 | 0 | 0 | 0 | 0 | 0 | 0
0 | 0 | 0 | 0 | 0 | 0 | 0 | 0 | 0
0 | 0 | 0 | 0 | 0 | 0 | 0 | 0 | 0
0 | 0 | 0 | 0 | 0 | 0 | 0 | 0 | 0
0 | 0 | 0 | 0 | 0 | 0 | 0 | 0 | 0
0 | 0 | 0 | 0 | 0 | 0 | 0 | 0 | 0
0 | 0 | 0 | 0 | 0 | 0 | 0 | 0 | 0
0 | 0 | 0 | 0 | 0 | 0 | 0 | 0 | 0
0 | 0 | 0 | 0 | 0 | 0 | 0 | 0 | 0
0 | 0 | 0 | 0 | 0 | 0 | 0 | 0 | 0
0 | 0 | 0 | 0 | 0 | 0 | 0 | 0 | 0
0 | 0 | 0 | 0 | 0 | 0 | 0 | 0 | 0
0 | 0 | 0 | 0 | 0 | 0 | 0 | 0 | 0
0 | 0 | 0 | 0 | 0 | 0 | 0 | 0 | 0
0 | 0 | 0 | 0 | 0 | 0 | 0 | 0 | 0
0 | 0 | 0 | 0 | 0 | 0 | 0 | 0 | 0
0 | 0 | 0 | 0 | 0 | 0 | 0 | 0 | 0
0 | 0 | 0 | 0 | 0 | 0 | 0 | 0 | 0
0 | 0 | 0 | 0 | 0 | 0 | 0 | 0 | 0
0 | 0 | 0 | 0 | 0 | 0 | 0 | 0 | 0
0 | 0 | 0 | 0 | 0 | 0 | 0 | 0 | 0
0 | 0 | 0 | 0 | 0 | 0 | 0 | 0 | 0
0 | 0 | 0 | 0 | 0 | 0 | 0 | 0 | 0
0 | 0 | 0 | 0 | 0 | 0 | 0 | 0 | 0
0 | 0 | 0 | 0 | 0 | 0 | 0 | 0 | 0
0 | 0 | 0 | 0 | 0 | 0 | 0 | 0 | 0
0 | 0 | 0 | 0 | 0 | 0 | 0 | 0 | 0
0 | 0 | 0 | 0 | 0 | 0 | 0 | 0 | 0
0 | 0 | 0 | 0 | 0 | 0 | 0 | 0 | 0
0 | 0 | 0 | 0 | 0 | 0 | 0 | 0 | 0
0 | 0 | 0 | 0 | 0 | 0 | 0 | 0 | 0
0 | 0 | 0 | 0 | 0 | 0 | 0 | 0 | 0
0 | 0 | 0 | 0 | 0 | 0 | 0 | 0 | 0
0 | 0 | 0 | 0 | 0 | 0 | 0 | 0 | 0
0 | 0 | 0 | 0 | 0 | 0 | 0 | 0 | 0
0 | 0 | 0 | 0 | 0 | 0 | 0 | 0 | 0
0 | 0 | 0 | 0 | 0 | 0 | 0 | 0 | 0
0 | 0 | 0 | 0 | 0 | 0 | 0 | 0 | 0
0 | 0 | 0 | 0 | 0 | 0 | 0 | 0 | 0
0 | 0 | 0 | 0 | 0 | 0 | 0 | 0 | 0
0 | 0 | 0 | 0 | 0 | 0 | 0 | 0 | 0
0 | 0 | 0 | 0 | 0 | 0 | 0 | 0 | 0
0 | 0 | 0 | 0 | 0 | 0 | 0 | 0 | 0
0 | 0 | 0 | 0 | 0 | 0 | 0 | 0 | 0
0 | 0 | 0 | 0 | 0 | 0 | 0 | 0 | 0
0 | 0 | 0 | 0 | 0 | 0 | 0 | 0 | 0
0 | 0 | 0 | 0 | 0 | 0 | 0 | 0 | 0
0 | 0 | 0 | 0 | 0 | 0 | 0 | 0 | 0
0 | 0 | 0 | 0 | 0 | 0 | 0 | 0 | 0
0 | 0 | 0 | 0 | 0 | 0 | 0 | 0 | 0
0 | 0 | 0 | 0 | 0 | 0 | 0 | 0 | 0
0 | 0 | 0 | 0 | 0 | 0 | 0 | 0 | 0
0 | 0 | 0 | 0 | 0 | 0 | 0 | 0 | 0
0 | 0 | 0 | 0 | 0 | 0 | 0 | 0 | 0
0 | 0 | 0 | 0 | 0 | 0 | 0 | 0 | 0
0 | 0 | 0 | 0 | 0 | 0 | 0 | 0 | 0
0 | 0 | 0 | 0 | 0 | 0 | 0 | 0 | 0
0 | 0 | 0 | 0 | 0 | 0 | 0 | 0 | 0
0 | 0 | 0 | 0 | 0 | 0 | 0 | 0 | 0
0 | 0 | 0 | 0 | 0 | 0 | 0 | 0 | 0
0 | 0 | 0 | 0 | 0 | 0 | 0 | 0 | 0
0 | 0 | 0 | 0 | 0 | 0 | 0 | 0 | 0
0 | 0 | 0 | 0 | 0 | 0 | 0 | 0 | 0
0 | 0 | 0 | 0 | 0 | 0 | 0 | 0 | 0
0 | 0 | 0 | 0 | 0 | 0 | 0 | 0 | 0
0 | 0 | 0 | 0 | 0 | 0 | 0 | 0 | 0
0 | 0 | 0 | 0 | 0 | 0 | 0 | 0 | 0
0 | 0 | 0 | 0 | 0 | 0 | 0 | 0 | 0
0 | 0 | 0 | 0 | 0 | 0 | 0 | 0 | 0
0 | 0 | 0 | 0 | 0 | 0 | 0 | 0 | 0
0 | 0 | 0 | 0 | 0 | 0 | 0 | 0 | 0
0 | 0 | 0 | 0 | 0 | 0 | 0 | 0 | 0
0 | 0 | 0 | 0 | 0 | 0 | 0 | 0 | 0
0 | 0 | 0 | 0 | 0 | 0 | 0 | 0 | 0
0 | 0 | 0 | 0 | 0 | 0 | 0 | 0 | 0
0 | 0 | 0 | 0 | 0 | 0 | 0 | 0 | 0
0 | 0 | 0 | 0 | 0 | 0 | 0 | 0 | 0
0 | 0 | 0 | 0 | 0 | 0 | 0 | 0 | 0
0 | 0 | 0 | 0 | 0 | 0 | 0 | 0 | 0
0 | 0 | 0 | 0 | 0 | 0 | 0 | 0 | 0
0 | 0 | 0 | 0 | 0 | 0 | 0 | 0 | 0
0 | 0 | 0 | 0 | 0 | 0 | 0 | 0 | 0
0 | 0 | 0 | 0 | 0 | 0 | 0 | 0 | 0
0 | 0 | 0 | 0 | 0 | 0 | 0 | 0 | 0
0 | 0 | 0 | 0 | 0 | 0 | 0 | 0 | 0
0 | 0 | 0 | 0 | 0 | 0 | 0 | 0 | 0
0 | 0 | 0 | 0 | 0 | 0 | 0 | 0 | 0
0 | 0 | 0 | 0 | 0 | 0 | 0 | 0 | 0
0 | 0 | 0 | 0 | 0 | 0 | 0 | 0 | 0
0 | 0 | 0 | 0 | 0 | 0 | 0 | 0 | 0
0 | 0 | 0 | 0 | 0 | 0 | 0 | 0 | 0
0 | 0 | 0 | 0 | 0 | 0 | 0 | 0 | 0
0 | 0 | 0 | 0 | 0 | 0 | 0 | 0 | 0
0 | 0 | 0 | 0 | 0 | 0 | 0 | 0 | 0
0 | 0 | 0 | 0 | 0 | 0 | 0 | 0 | 0
0 | 0 | 0 | 0 | 0 | 0 | 0 | 0 | 0
0 | 0 | 0 | 0 | 0 | 0 | 0 | 0 | 0
0 | 0 | 0 | 0 | 0 | 0 | 0 | 0 | 0
0 | 0 | 0 | 0 | 0 | 0 | 0 | 0 | 0
0 | 0 | 0 | 0 | 0 | 0 | 0 | 0 | 0
0 | 0 | 0 | 0 | 0 | 0 | 0 | 0 | 0
0 | 0 | 0 | 0 | 0 | 0 | 0 | 0 | 0
0 | 0 | 0 | 0 | 0 | 0 | 0 | 0 | 0
0 | 0 | 0 | 0 | 0 | 0 | 0 | 0 | 0
0 | 0 | 0 | 0 | 0 | 0 | 0 | 0 | 0
0 | 0 | 0 | 0 | 0 | 0 | 0 | 0 | 0
0 | 0 | 0 | 0 | 0 | 0 | 0 | 0 | 0
0 | 0 | 0 | 0 | 0 | 0 | 0 | 0 | 0
0 | 0 | 0 | 0 | 0 | 0 | 0 | 0 | 0
0 | 0 | 0 | 0 | 0 | 0 | 0 | 0 | 0

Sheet: csv-import
Reference | Quantity | Value | Footprint | Datasheet | Comments | Distributor | Distributor PN | MPN | Manufacturer | DNP
C12 C13 | 2 | 220uF 25V | Capacitor_THT:CP_Radial_D8.0mm_P3.50mm | https://eu.mouser.com/datasheet/2/212/KEM_A4055_ESE-1140496.pdf |  | Elfa | 301-51-797 | ESE227M025AG3AA | KEMET
C14 C15 | 2 | 10uF >17 V X7R | Capacitor_SMD:C_0805_2012Metric | ~ |  | RS | 184-3756 | TMK212BBJ106MG-T | Taiyo Yuden
C16 C17 | 2 | 22uF >6V X7R | Capacitor_SMD:C_0805_2012Metric | ~ |  | RS | 691-1177 | C0805C226M9PACTU | Kemet
C2 C6 C1 C7 C8 C3 C10 C18 C23 | 9 | 0.1uF | Capacitor_SMD:C_0603_1608Metric | ~
C4 C5 C20 C25 | 4 | 1uF | Capacitor_SMD:C_0603_1608Metric | ~
C9 C19 C24 | 3 | ? | Capacitor_SMD:C_0603_1608Metric | ~ |  |  |  |  |  | DNP
D1 | 1 | D_TVS | Diode_SMD:D_SMB | https://www.littelfuse.com/~/media/electronics/datasheets/tvs_diodes/littelfuse_tvs_diode_tpsmb_datasheet.pdf.pdf |  | Mouser | 576-TPSMB20CA | TPSMB20CA | Littlefuse
D13 | 1 | LED GREEN | LED_SMD:LED_0603_1608Metric | ~
D2 | 1 | 12V | Diode_SMD:D_SOD-123 | ~ |  | CASE |  | MMSZ5242B-G3-08 | Vishay
D3 D5 D4 | 3 | 5.1V | Diode_SMD:D_SOD-123 | ~ |  | CASE |  | MMSZ5232B-7-F | Diodes Inc.
D6 | 1 | ESDA6V1-5SC6 | Package_TO_SOT_SMD:SOT-23-6 | www.st.com/resource/en/datasheet/esda6v1-5sc6.pdf |  | RS | 250-066 | ESDA6V1-5SC6 | ST
D7 D9 D11 | 3 | LED RED | LED_SMD:LED_0603_1608Metric | ~
D8 D10 D12 | 3 | D_Schottky | Diode_SMD:D_SOD-123 | https://datasheet.octopart.com/1N5819HW-7-F-Diodes-Inc.-datasheet-8332965.pdf |  | Mouser | 621-1N5819HW-F | 1N5819HW | Diodes Incorporated
H1 H3 H2 H4 | 4 | MountingHole_Pad | MountingHole:MountingHole_2.7mm_M2.5_Pad_Via | ~
J1 | 1 | NanoFit 02x02 | local:02x02_vertical_105310-1204 | ~ |  | Mouser | 538-105310-1204 | 105310-1204 | Molex
J2 | 1 | Micro Lock 02x04 | local:Molex_Micro-Lock_5054330871_2x4_P1.25_Vertical | ~ | Connetor for power on/off and LED indication | RS | 186-5193 | 5054330871 | Molex
J3 | 1 | ZF5S-30-03-T-WT | local:ZF5S-30-03-T-WT | http://suddendocs.samtec.com/productspecs/zf5s.pdf | To FP-PCBA | Mouser | 200-ZF5S3003TWTTR | ZF5S-30-03-T-WT-TR | Samtec
J4 | 1 | Micro Lock 01x09 | local:01x09_vertical_2059570971 | ~ |  | Elfa | 301-76-000 | 205957-0971 | Molex
J5 | 1 | Conn_02x20_Odd_Even | Connector_Samtec_HLE_SMD:Samtec_HLE-120-02-xxx-DV-BE-A_2x20_P2.54mm_Horizontal | ~ |  | Mouser | 200-HLE12002FDVBEA | HLE-120-02-F-DV-BE-A | Samtec
Q1 | 1 | DMP3013SFV | Package_SON:Diodes_PowerDI3333-8 | https://www.diodes.com/assets/Datasheets/DMP3013SFV.pdf |  | Mouser | 621-DMP3013SFV-7 | DMP3013SFV-7 | Diodes Incorporated
Q2 Q4 Q5 Q3 Q6 Q7 | 6 | BSS138 | Package_TO_SOT_SMD:SOT-23 | https://www.fairchildsemi.com/datasheets/BS/BSS138.pdf
R11 R23 | 2 | 1.6M | Resistor_SMD:R_0603_1608Metric | ~
R13 R17 R15 | 3 | 27k | Resistor_SMD:R_0603_1608Metric | ~
R2 | 1 | 1M | Resistor_SMD:R_0603_1608Metric | ~
R22 R21 R20 R19 R18 | 5 | 160 | Resistor_SMD:R_0603_1608Metric | ~
R25 | 1 | 18k | Resistor_SMD:R_0603_1608Metric | ~
R26 R30 | 2 | 39k | Resistor_SMD:R_0603_1608Metric | ~
R27 | 1 | 2k | Resistor_SMD:R_0603_1608Metric | ~
R28 | 1 | 270k | Resistor_SMD:R_0603_1608Metric | ~
R29 | 1 | 30k | Resistor_SMD:R_0603_1608Metric | ~
R31 | 1 | 1.2k | Resistor_SMD:R_0603_1608Metric | ~
R32 | 1 | 4.3k | Resistor_SMD:R_0603_1608Metric | ~
R33 | 1 | 10k | Resistor_SMD:R_0603_1608Metric | ~
R34 | 1 | 1.1k | Resistor_SMD:R_0603_1608Metric | ~
R35 | 1 | 270 | Resistor_SMD:R_0603_1608Metric | ~
R45 R38 R39 R42 R43 | 5 | 1k | Resistor_SMD:R_0603_1608Metric | ~
R5 R3 R12 R4 R1 R10 R9 R16 R14 R6 R44 R24 R36 R37 R40 R41 | 16 | 100k | Resistor_SMD:R_0603_1608Metric | ~
R7 | 1 | 0 | Resistor_SMD:R_0603_1608Metric | ~
R8 | 1 | ? | Resistor_SMD:R_0603_1608Metric | ~ |  |  |  |  |  | DNP
SW1 SW2 | 2 | SW_Push | local:KMR621NGLFS | https://datasheet.octopart.com/KMR621NGLFS-C%26K-Components-datasheet-117009927.pdf |  | CASE |  | KMR621NGLFS | C&K Components
TP1 TP2 TP3 TP4 TP21 TP20 TP19 TP18 TP17 TP16 TP15 TP14 TP13 TP12 TP11 TP10 TP9 TP8 TP7 TP6 TP5 TP22 TP23 TP24 | 24 | TestPoint | TestPoint:TestPoint_THTPad_D1.0mm_Drill0.5mm | ~
U1 | 1 | MCP23017_ML | Package_DFN_QFN:QFN-28-1EP_6x6mm_P0.65mm_EP4.25x4.25mm | http://ww1.microchip.com/downloads/en/DeviceDoc/20001952C.pdf |  | RS | 687-8773 | MCP23017-E/ML | Microchip
U2 | 1 | LTC2955xDDB-1 | Package_DFN_QFN:DFN-10-1EP_2x3mm_P0.5mm_EP0.64x2.4mm | https://www.analog.com/media/en/technical-documentation/data-sheets/2955fa.pdf |  | RS | 884-6927 | LTC2955IDDB-1#TRMPBF | LT
U3 | 1 | ADS1015BQDGSRQ1 | Package_SO:TSSOP-10_3x3mm_P0.5mm | http://www.ti.com/lit/ds/symlink/ads1113.pdf |  | Mouser | 595-ADS1015BQDGSRQ1 | ADS1015BQDGSRQ1 | TI
U4 | 1 | TPS25940x-Q1 | Package_DFN_QFN:QFN-20-1EP_3x4mm_P0.5mm_EP1.65x2.65mm_ThermalVias | http://www.ti.com/lit/ds/symlink/tps25940-q1.pdf | Latching and automotive variant | Mouser | 595-TPS25940LQRVCRQ1 | TPS25940LQRVCRQ1 | TI
U5 | 1 | TPSM84624MOLR | local:TPSM84624MOLR | https://www.ti.com/lit/gpn/tpsm84624 |  | Mouser | 595-TPSM84624MOLR | TPSM84624MOLR | TI
U6 U7 | 2 | TPS2595xx | Package_SON:WSON-8-1EP_2x2mm_P0.5mm_EP0.9x1.6mm_ThermalVias | https://www.ti.com/lit/gpn/tps2595 |  | Mouser | 595-TPS259570DSGR | TPS259570DSGR | TI

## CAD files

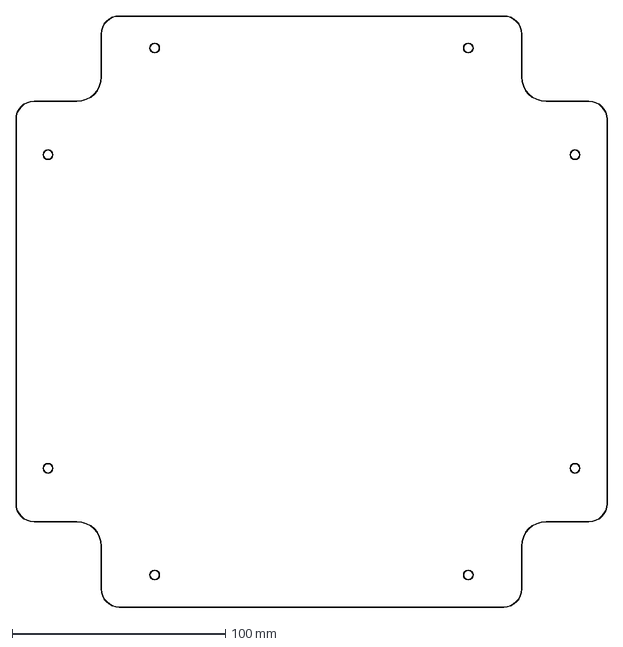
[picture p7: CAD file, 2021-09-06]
CAD/InventorProject/Manufacturing/AcrylicPlateForFixturePlate_NewHoles.ipt.dxf
277.0 x 277.0 mm

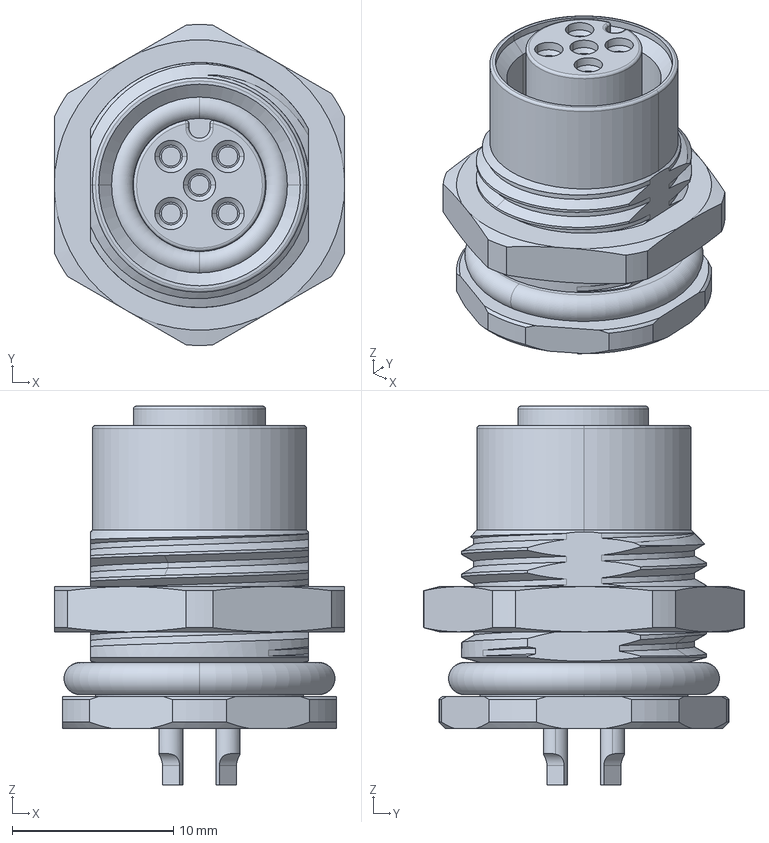
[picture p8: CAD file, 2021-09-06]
CAD/InventorProject/Back_Panel/Connectors/c-t4131012041-000/c-t4131012041-000.stp
18.0 x 19.9 x 23.5 mm

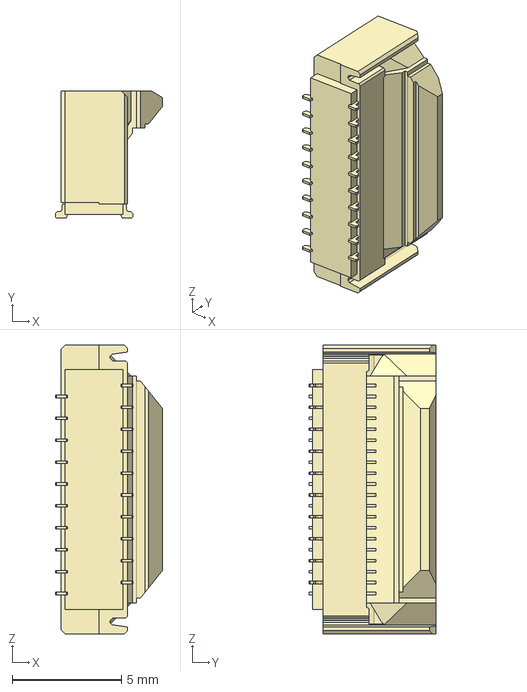
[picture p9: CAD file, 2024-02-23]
CAD/InventorProject/Back_Panel/Connectors/FH40-20S-0.5SV/FH40-20S-0.5SV.stp
4.90 x 5.80 x 13.2 mm

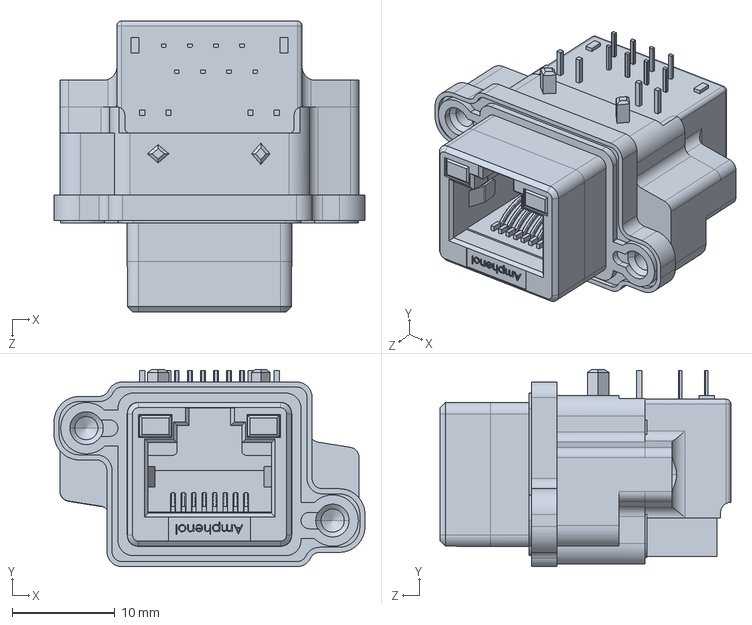
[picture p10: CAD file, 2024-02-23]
CAD/InventorProject/Back_Panel/Connectors/M-MRJR-538X-01/M-MRJR-538X-01-REVT1.STEP
30.3 x 19.2 x 28.3 mm

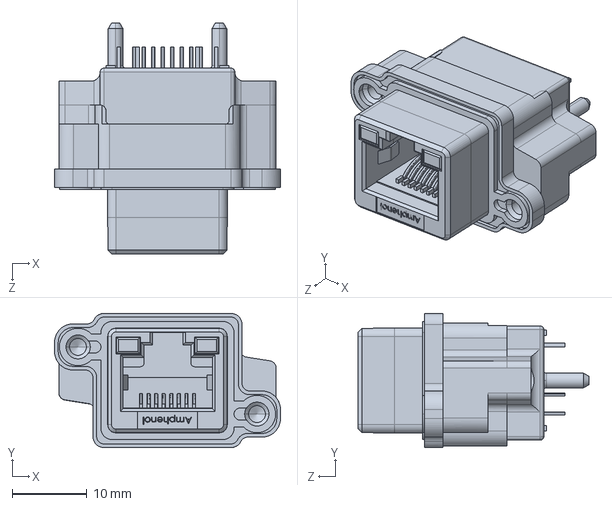
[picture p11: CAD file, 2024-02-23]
CAD/InventorProject/Back_Panel/Connectors/M-MRJR-548X-0F/M-MRJR-548X-0F.STEP
30.3 x 18.0 x 31.0 mm

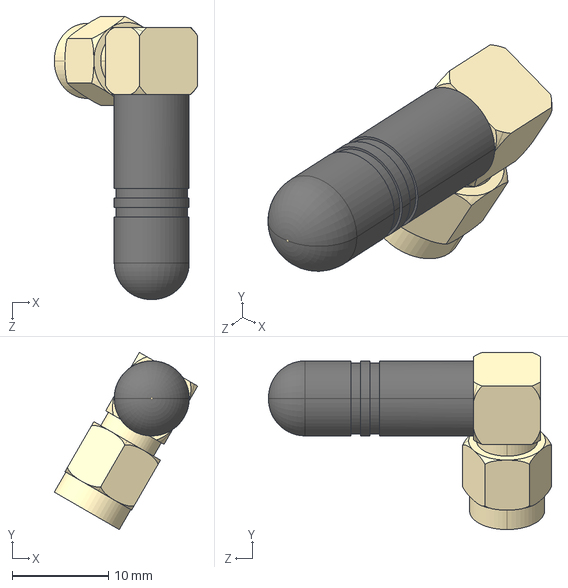
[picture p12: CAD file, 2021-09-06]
CAD/InventorProject/Back_Panel/Other/GW.26.0152/GW.26.0152_web.step
14.9 x 18.4 x 29.4 mm

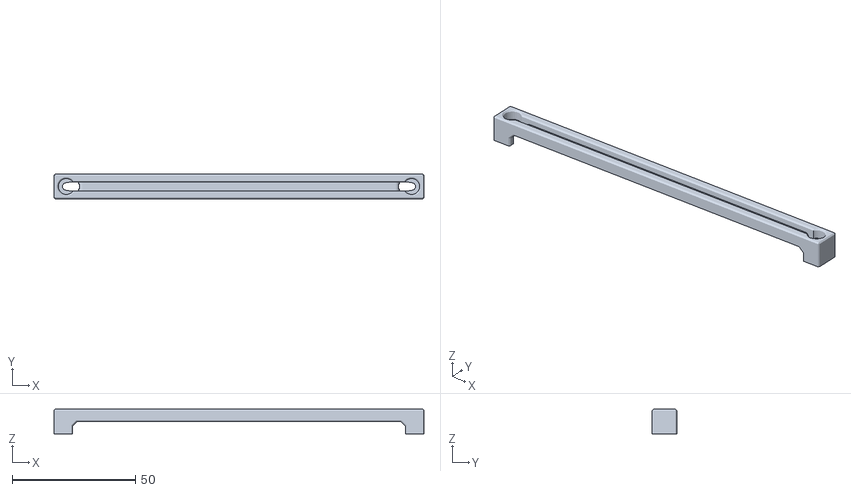
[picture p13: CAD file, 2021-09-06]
CAD/InventorProject/Manufacturing/ModuleBracket_Slot.stl
150.0 x 10.0 x 10.0

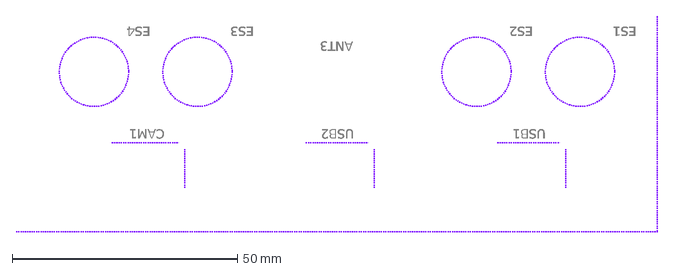
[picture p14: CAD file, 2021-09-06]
CAD/InventorProject/Manufacturing/UnicornPaneler/FrontText_V2_WaveRunner.dxf
ES1
ES2
ES4
ES3
USB1
USB2
CAM1
ANT3

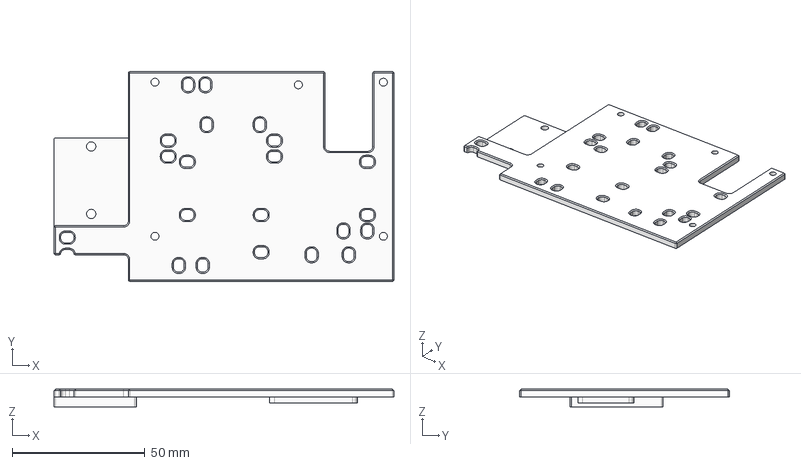
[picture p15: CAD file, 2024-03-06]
CAD/InventorProject/Other/Cable_Fastener_10Gbit.stp
128.0 x 79.0 x 6.60 mm

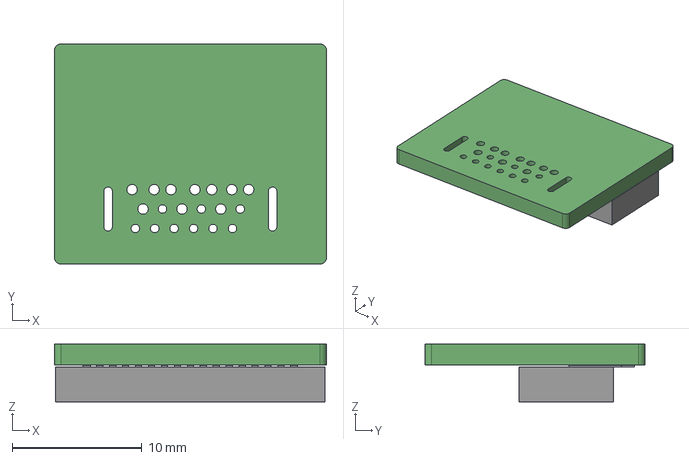
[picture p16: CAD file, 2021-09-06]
CAD/InventorProject/PCB_Assemblies/PCBA_Models/CAMERA_CON_PCBA/CAMERA_CON_PCBA.step
21.0 x 17.0 x 4.45 mm

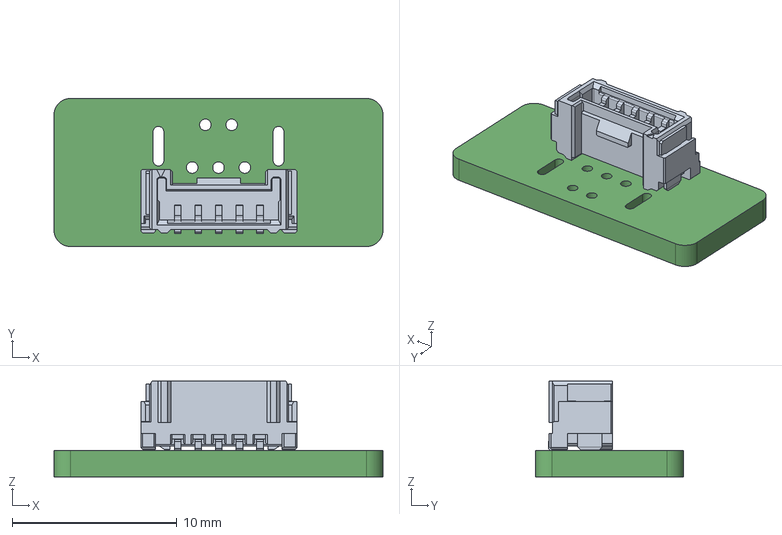
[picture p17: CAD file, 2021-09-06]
CAD/InventorProject/PCB_Assemblies/PCBA_Models/MiniUSB-ADAPTER-PCBA/MiniUSB_ADAPTER-PCBA.step
20.0 x 9.00 x 5.81 mm

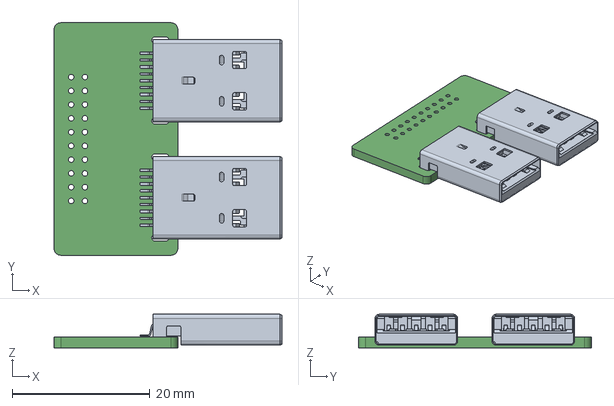
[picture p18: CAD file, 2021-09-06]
CAD/InventorProject/PCB_Assemblies/PCBA_Models/USB-EXT/USB-EXT.step
33.1 x 33.8 x 4.87 mm

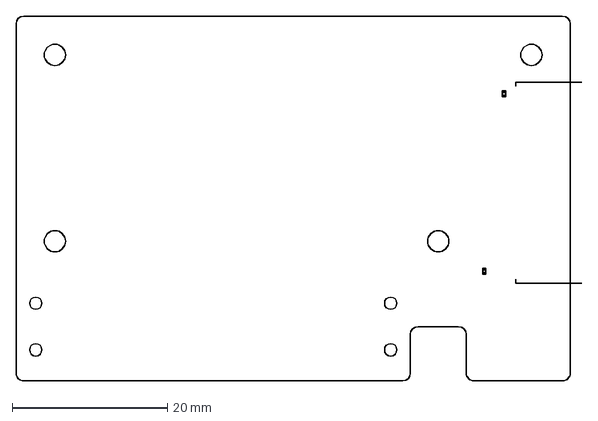
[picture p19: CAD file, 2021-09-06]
CAD/InventorProject/PCB_Outlines/PWR_PCBA_OUTLINE.dxf
72.9 x 47.0 mm

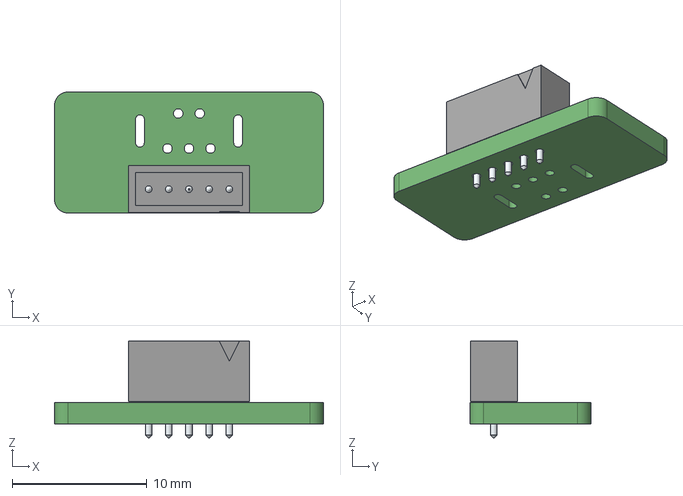
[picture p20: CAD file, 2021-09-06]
PCB/MiniUSB_ADAPTER-PCBA/hw/MiniUSB_ADAPTER-PCBA.step
20.0 x 9.00 x 7.20 mm

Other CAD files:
CAD/InventorProject/Manufacturing/CNC_VacuumCleaner_Adapter.stl
CAD/InventorProject/Manufacturing/UnicornPaneler/EngravingJig.dxf
CAD/InventorProject/PCB_Outlines/ES_MODULE_OUTLINE.dxf
CAD/InventorProject/Manufacturing/FrontText.dxf
CAD/InventorProject/Back_Panel/Back_Panel_Assembly.iam
CAD/InventorProject/Back_Panel/Back_Panel_Assembly_10Gbit.iam
CAD/InventorProject/Back_Panel/Connectors/1424134/1424134-3d-model-1-en.stp
CAD/InventorProject/Back_Panel/Connectors/1424134/1424134.iam
CAD/InventorProject/Back_Panel/Connectors/1424134/415371.ipt
CAD/InventorProject/Back_Panel/Connectors/1424134/BP-L23HAGAAX_XX_SW0001.ipt
CAD/InventorProject/Back_Panel/Connectors/82-4551.1123/36059.iam
CAD/InventorProject/Back_Panel/Connectors/82-4551.1123/36059_01.ipt
CAD/InventorProject/Back_Panel/Connectors/82-4551.1123/36059_02.ipt
CAD/InventorProject/Back_Panel/Connectors/82-4551.1123/36059_03.ipt
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

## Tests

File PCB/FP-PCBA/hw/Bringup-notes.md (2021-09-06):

# Bringup Notes FP-PCBA

## REV 1

* Change Outline to account for micro usb on Jetson module
* Change mounting hole to slot to account for mounting tolerances
* Look into better solution for FFC connector placement -  currently bends to much to stay well seated.
  * How to solve this without using dual sided SMD? Check how easy it is to solder the FFC connector by hand.
* Consider adding power LED

## REV 2

* D+ and D- are flipped for the 4x UART IC
* Drivers are working for UART IC

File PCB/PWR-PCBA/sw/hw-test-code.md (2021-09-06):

# Hardware Test Code Notes

[Guide to get Circuit Python Installed on the Jetson Nano](https://learn.adafruit.com/circuitpython-libraries-on-linux-and-the-nvidia-jetson-nano/circuitpython-dragonboard)

ADC seems to be working

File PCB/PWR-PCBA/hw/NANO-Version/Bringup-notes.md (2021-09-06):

# Bring up notes PWR-PCBA

## REV1

### Identified problems and suggested solutions:

* Main connector to Jetson is flipped
* Add some more test points on Push Button Controller
* Consider changing 9 pin GPIO connector to dual row variant (was blown away when soldering)
  * Made new soldering attempt and stays put if tapped down into the solder paste
* NET ON_INDC is not routed out to a connector and needs a pull-up (100k to 5V)
* Add power LED to know when power is on
* Configure fault LED to only light up when enable is active (enable high is only 1 V so care needs to be taken when designing this - **Datasheet and measurement shows this is around 4 V which is enough to drive a nmos gate**)

### Suspected problems to be looked into:

* ~~LED is not working to indicate fault on 2 A 12 V eFuse (but it is working on the identical 5V - check if LED is flipped in the wrong direction)~~
  * Problem solved - bad solder joint on one eFuse

### Tested and working:

* Both small 2A 5V and 12 V eFuses can be reset via the button.
* Primary eFuse (consider increasing resistance for fault led - standby power consumption should be low). 
* Both I2C devices detected with i2cdetect
* External power indication LED
* IO expander via i2c [Adafruit Github](https://github.com/adafruit/Adafruit-Raspberry-Pi-Python-Code/tree/legacy)
  * Checked with CLI i2cset [(guide)](https://www.raspberrypi-spy.co.uk/2013/07/how-to-use-a-mcp23017-i2c-port-expander-with-the-raspberry-pi-part-1/)

### Not checked

* ADC - calculations and conversion to actual voltage/current

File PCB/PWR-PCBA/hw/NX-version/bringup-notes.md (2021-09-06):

# Bring-up Notes PWR-PCBA NX-Version

## REV 1

### Problems

* Problems with how power should be supplied to Jetson Xavier
  3V3 is no longer generated from the 5V rail as was the case with the Jetson Nano. Instead they are independently generated from the main 9-19 V input rail.
  * Actions:
    * Current boards will be reworked to include wiring for supplying 12 V to the auxiliary dc in connector on the Jetson NX. This has been tested and shown to be a doable workaround.  For a more secure connection a solder cup pin terminal will be used for the wire to board connection. Care needs to be taken as clearance to the m2 ssd on the NX backside is tight. Additionally a wire to wire connector will be added between the NX and PWR-PCBA for allowing disconnections.
      The 5V rail also need to be disconnected from the NX as this will otherwise have two regulators powering the same rail. This should preferably be done by removing the 5V pins from the 40 pin board to board connector.
    * A new board revision:
      Adding a new 2 pin Nano fit connector to backside of board for connection of eFused 12 V to NX power input. NX side will use solder cup pin header for connection.
      Disconnecting 5V DC/DC from NX. This will now instead be dedicated to powering expansion board on FP-PCBA.

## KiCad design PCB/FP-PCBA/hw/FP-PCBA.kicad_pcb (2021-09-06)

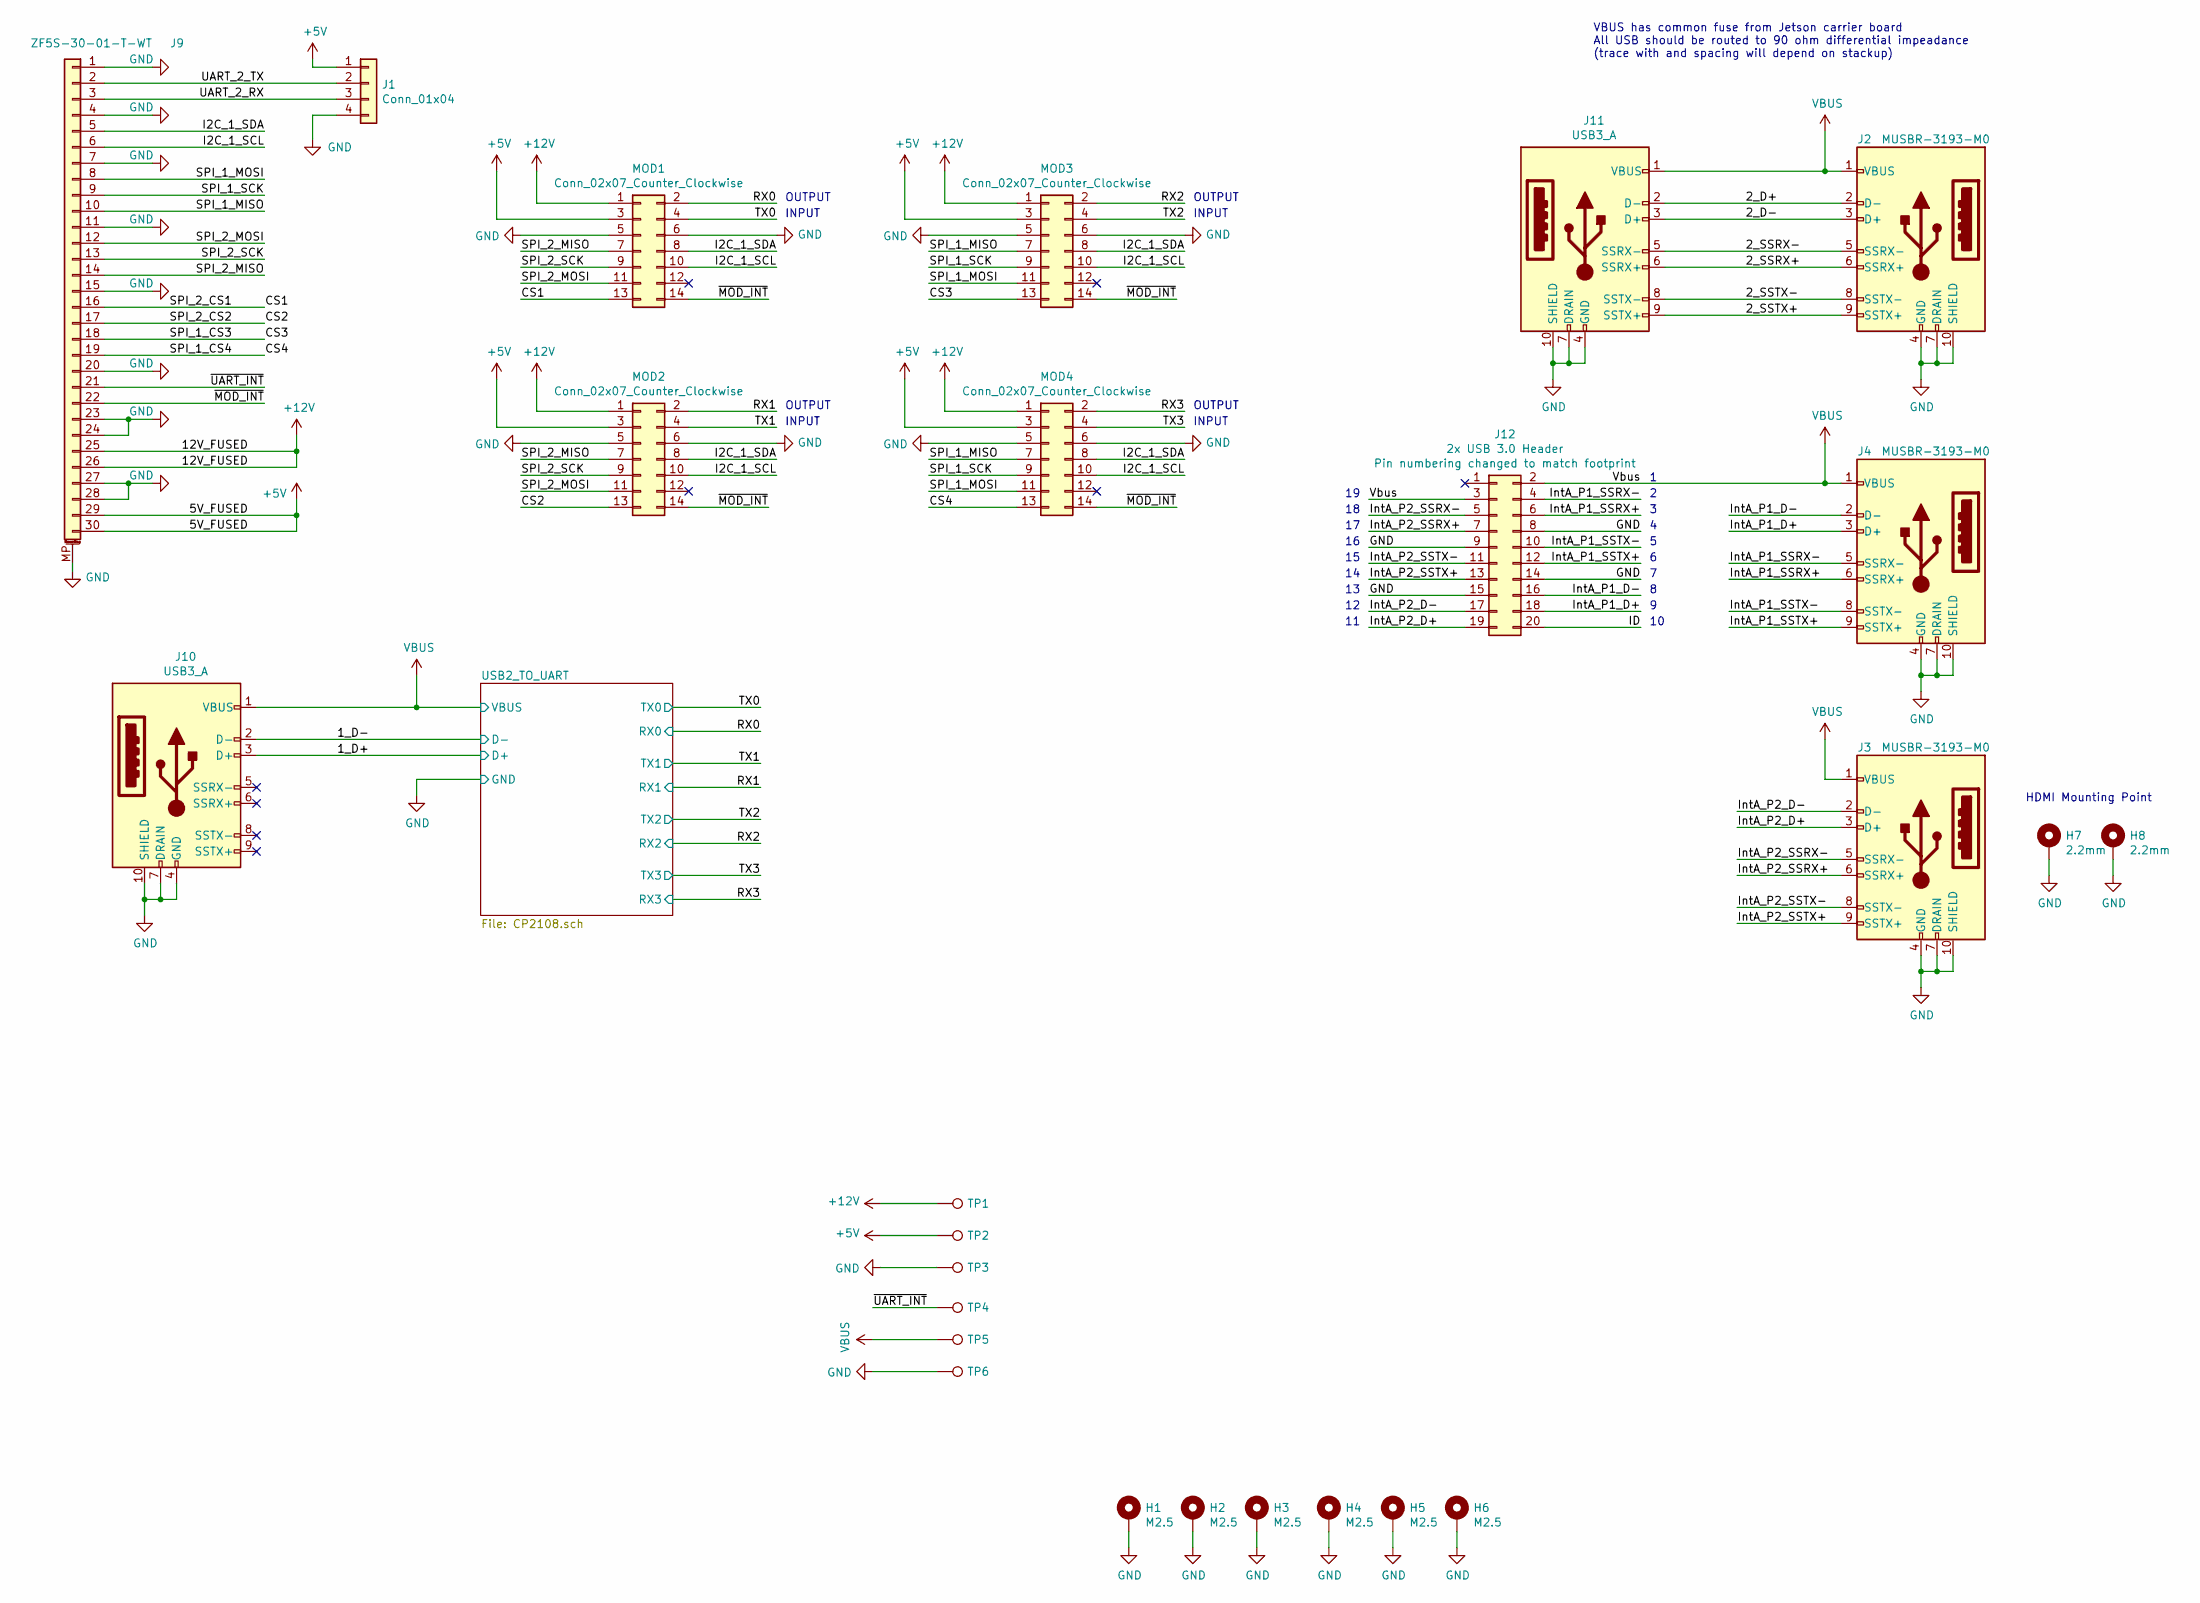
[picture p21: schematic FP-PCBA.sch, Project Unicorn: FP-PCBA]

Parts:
H1, H2, H3, H4: M2.5; MountingHole_2.7mm_M2.5_Pad_Via
H5, H6: M2.5; Slotted_2mm_M2.5_Vias
H7, H8: 2.2mm; MountingHole_2.2mm_M2_Pad
J1: Conn_01x04; Molex_Micro_Lock_1x4_Vertical_5055680471; MPN 505568-0471
J2, J3, J4: MUSBR-3193-M0; MUSBR3193M0; MPN MUSBR-3193-M0
J9: ZF5S-30-01-T-WT; ZF5S-30-03-T-WT; MPN ZF5S-30-03-T-WT
J10, J11: USB3_A; USB3_A_Plug_AMPHENOL_GSB316441CEU; MPN GSB316441CEU
J12: 2x USB 3.0 Header; PinHeader_2x10_P2.00mm_Vertical; MPN TW-10-11-T-D-250-080
MOD1, MOD2, MOD3, MOD4: Conn_02x07_Counter_Clockwise; Samtec_HLE-107-02-xxx-DV-BE-A_2x07_P2.54mm_Horizontal; MPN HLE-107-02-F-DV-BE-A-K-TR
TP1, TP2, TP3, TP4, TP5, TP6: TestPoint; TestPoint_THTPad_D1.0mm_Drill0.5mm

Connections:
+5V: J1.1, J9.29, J9.30, MOD1.3, MOD2.3, MOD3.3, MOD4.3, TP2.1
+12V: J9.25, J9.26, MOD1.1, MOD2.1, MOD3.1, MOD4.1, TP1.1
/1_D+: J10.3 (D+); also elsewhere on the board
/1_D-: J10.2 (D-); also elsewhere on the board
/2_D+: J2.2 (D-), J11.2 (D-)
/2_D-: J2.3 (D+), J11.3 (D+)
/2_SSRX+: J2.6 (SSRX+), J11.6 (SSRX+)
/2_SSRX-: J2.5 (SSRX-), J11.5 (SSRX-)
/2_SSTX+: J2.9 (SSTX+), J11.9 (SSTX+)
/2_SSTX-: J2.8 (SSTX-), J11.8 (SSTX-)
/CS1: J9.16, MOD1.13
/CS2: J9.17, MOD2.13
/CS3: J9.18, MOD3.13
/CS4: J9.19, MOD4.13
/I2C_1_SCL: J9.6, MOD1.10, MOD2.10, MOD3.10, MOD4.10
/I2C_1_SDA: J9.5, MOD1.8, MOD2.8, MOD3.8, MOD4.8
/ID: J12.20
/IntA_P1_D+: J4.3 (D+), J12.18
/IntA_P1_D-: J4.2 (D-), J12.16
/IntA_P1_SSRX+: J4.6 (SSRX+), J12.6
/IntA_P1_SSRX-: J4.5 (SSRX-), J12.4
/IntA_P1_SSTX+: J4.9 (SSTX+), J12.12
/IntA_P1_SSTX-: J4.8 (SSTX-), J12.10
/IntA_P2_D+: J3.3 (D+), J12.19
/IntA_P2_D-: J3.2 (D-), J12.17
/IntA_P2_SSRX+: J3.6 (SSRX+), J12.7
/IntA_P2_SSRX-: J3.5 (SSRX-), J12.5
/IntA_P2_SSTX+: J3.9 (SSTX+), J12.13
/IntA_P2_SSTX-: J3.8 (SSTX-), J12.11
/RX0: MOD1.2; also elsewhere on the board
/RX1: MOD2.2; also elsewhere on the board
/RX2: MOD3.2; also elsewhere on the board
/RX3: MOD4.2; also elsewhere on the board
/SPI_1_MISO: J9.10, MOD3.7, MOD4.7
/SPI_1_MOSI: J9.8, MOD3.11, MOD4.11
/SPI_1_SCK: J9.9, MOD3.9, MOD4.9
/SPI_2_MISO: J9.14, MOD1.7, MOD2.7
/SPI_2_MOSI: J9.12, MOD1.11, MOD2.11
/SPI_2_SCK: J9.13, MOD1.9, MOD2.9
/TX0: MOD1.4; also elsewhere on the board
/TX1: MOD2.4; also elsewhere on the board
/TX2: MOD3.4; also elsewhere on the board
/TX3: MOD4.4; also elsewhere on the board
/UART_2_RX: J1.3, J9.3
/UART_2_TX: J1.2, J9.2
/~MOD_INT: J9.22, MOD1.14, MOD2.14, MOD3.14, MOD4.14
/~UART_INT: J9.21, TP4.1
GND: H1.1, H2.1, H3.1, H4.1, H5.1, H6.1, H7.1, H8.1, J1.4, J2.4 (GND), J2.7 (DRAIN), J2.10 (SHIELD), J3.4 (GND), J3.7 (DRAIN), J3.10 (SHIELD), J4.4 (GND), J4.7 (DRAIN), J4.10 (SHIELD), J9.1, J9.4, J9.7, J9.11, J9.15, J9.20, J9.23, J9.24, J9.27, J9.28, J9.MP (MountPin), J10.4 (GND), J10.7 (DRAIN), J10.10 (SHIELD), J11.4 (GND), J11.7 (DRAIN), J11.10 (SHIELD), J12.8, J12.9, J12.14, J12.15, MOD1.5, MOD1.6, MOD2.5, MOD2.6, MOD3.5, MOD3.6, MOD4.5, MOD4.6, TP3.1, TP6.1; also elsewhere on the board
VBUS: J2.1 (VBUS), J3.1 (VBUS), J4.1 (VBUS), J10.1 (VBUS), J11.1 (VBUS), J12.2, J12.3, TP5.1; also elsewhere on the board

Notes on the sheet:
VBUS has common fuse from Jetson carrier board All USB should be routed to 90 ohm differential impeadance (trace with and spacing will depend on stackup)
HDMI Mounting Point
OUTPUT
INPUT

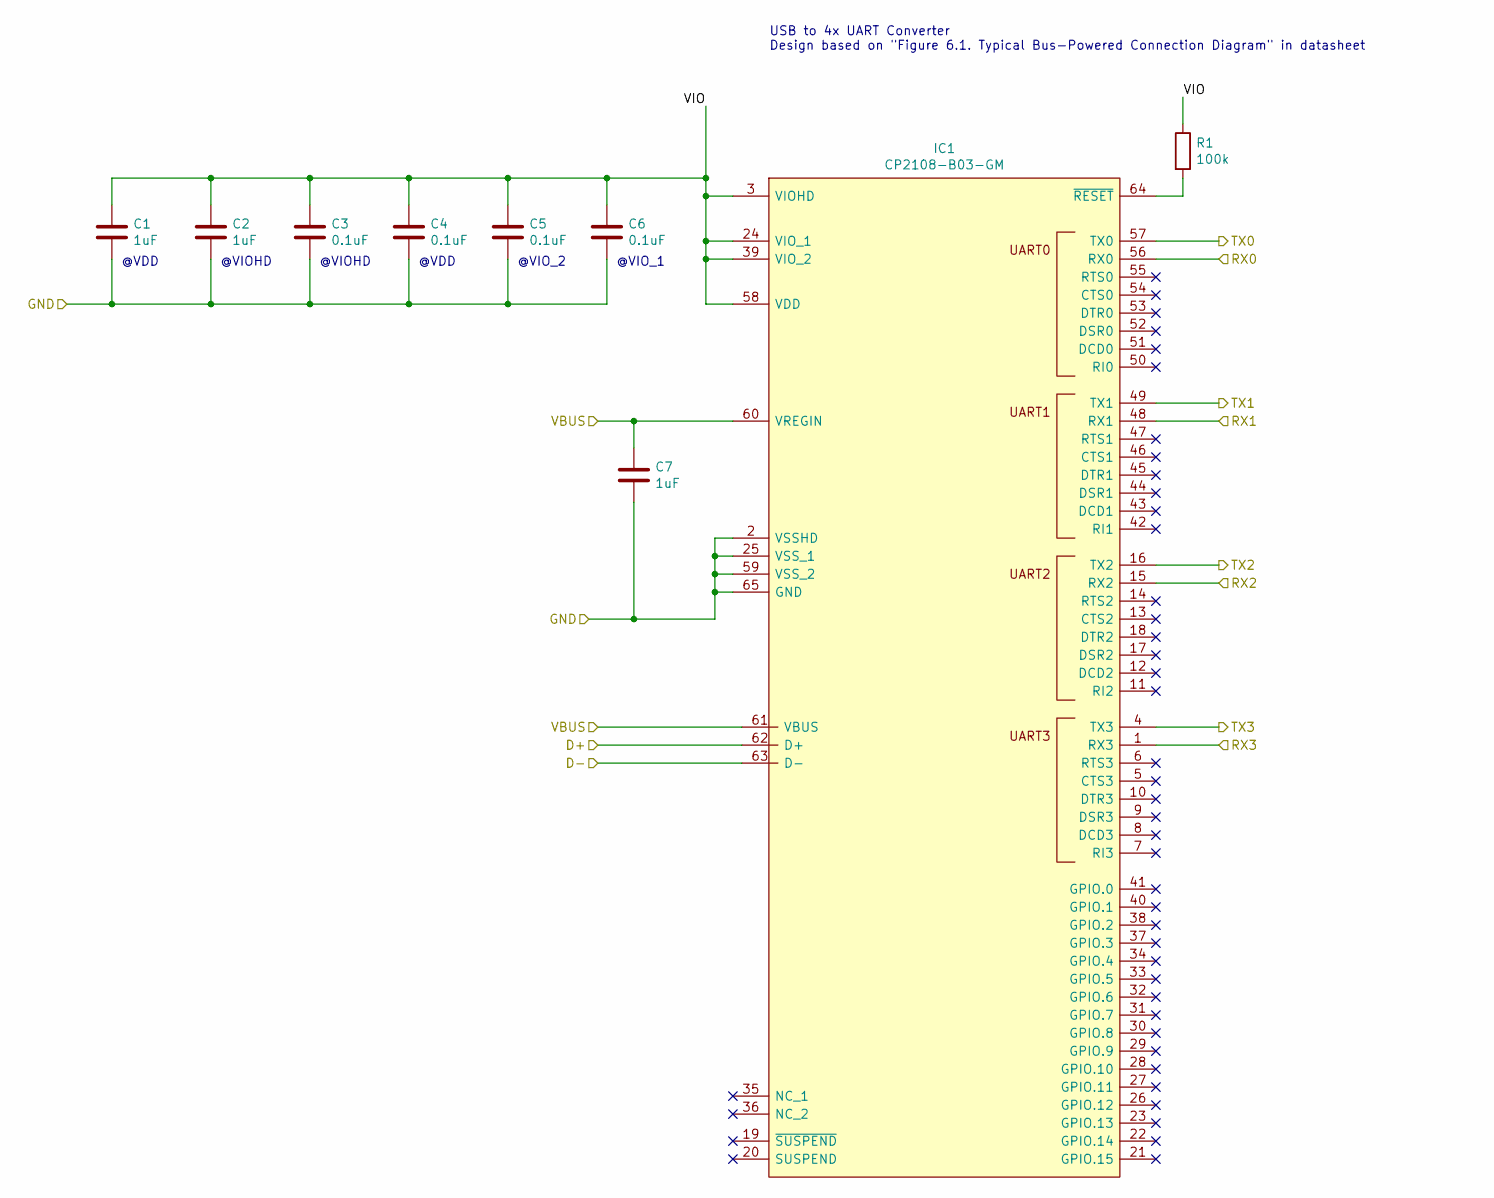
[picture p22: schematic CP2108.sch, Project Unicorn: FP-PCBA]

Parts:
C1, C2, C7: 1uF; C_0603_1608Metric; MPN C0603C105K4RAC7411
C3, C4, C5, C6: 0.1uF; C_0603_1608Metric; MPN 06033C104KAT4A
IC1: CP2108-B03-GM; MPN CP2108-B02-GMR
R1: 100k; R_0603_1608Metric

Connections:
/1_D+: IC1.62 (D+); also elsewhere on the board
/1_D-: IC1.63 (D-); also elsewhere on the board
/RX0: IC1.56 (RX0); also elsewhere on the board
/RX1: IC1.48 (RX1); also elsewhere on the board
/RX2: IC1.15 (RX2); also elsewhere on the board
/RX3: IC1.1 (RX3); also elsewhere on the board
/TX0: IC1.57 (TX0); also elsewhere on the board
/TX1: IC1.49 (TX1); also elsewhere on the board
/TX2: IC1.16 (TX2); also elsewhere on the board
/TX3: IC1.4 (TX3); also elsewhere on the board
/USB2_TO_UART/VIO: C1.1, C2.1, C3.1, C4.1, C5.1, C6.1, IC1.3 (VIOHD), IC1.24 (VIO_1), IC1.39 (VIO_2), IC1.58 (VDD), R1.1
GND: C1.2, C2.2, C3.2, C4.2, C5.2, C6.2, C7.2, IC1.2 (VSSHD), IC1.25 (VSS_1), IC1.59 (VSS_2), IC1.65 (GND); also elsewhere on the board
unnamed: IC1.64 (~RESET), R1.2
VBUS: C7.1, IC1.60 (VREGIN), IC1.61 (VBUS); also elsewhere on the board

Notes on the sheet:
@VIO_1
@VIO_2
@VDD
@VIOHD
USB to 4x UART Converter Design based on "Figure 6.1. Typical Bus-Powered Connection Diagram" in datasheet

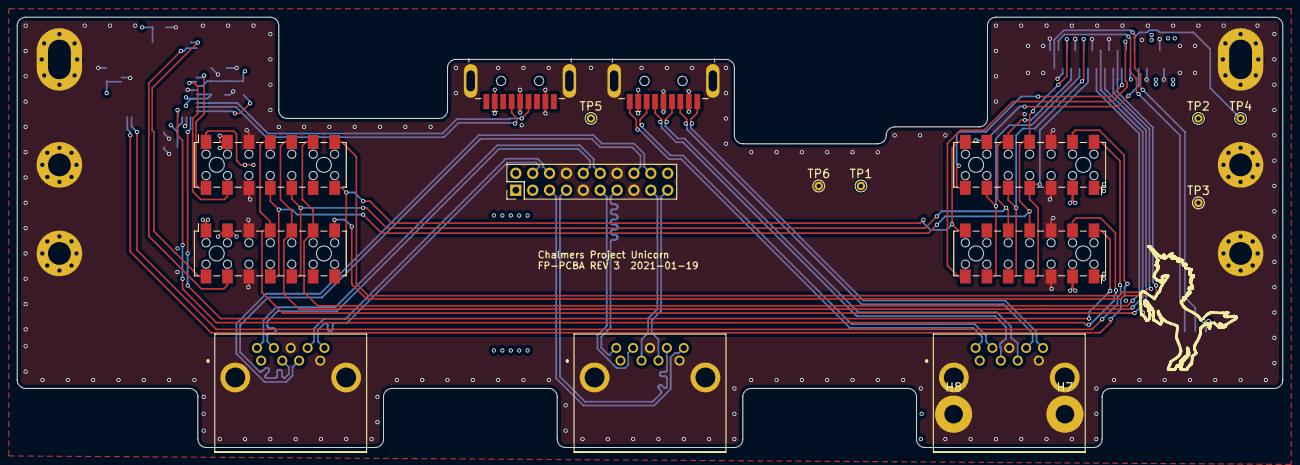
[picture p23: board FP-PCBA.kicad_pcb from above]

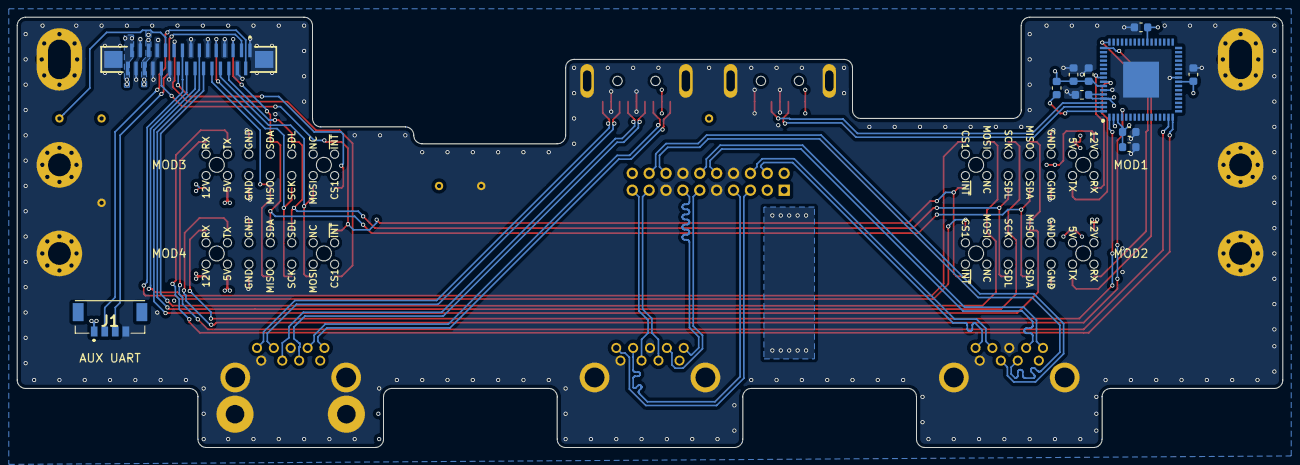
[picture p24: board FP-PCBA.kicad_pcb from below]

Board: 4 copper layers, 150.0 x 51.0 mm, 35 parts (11 on the bottom side), 50 nets.

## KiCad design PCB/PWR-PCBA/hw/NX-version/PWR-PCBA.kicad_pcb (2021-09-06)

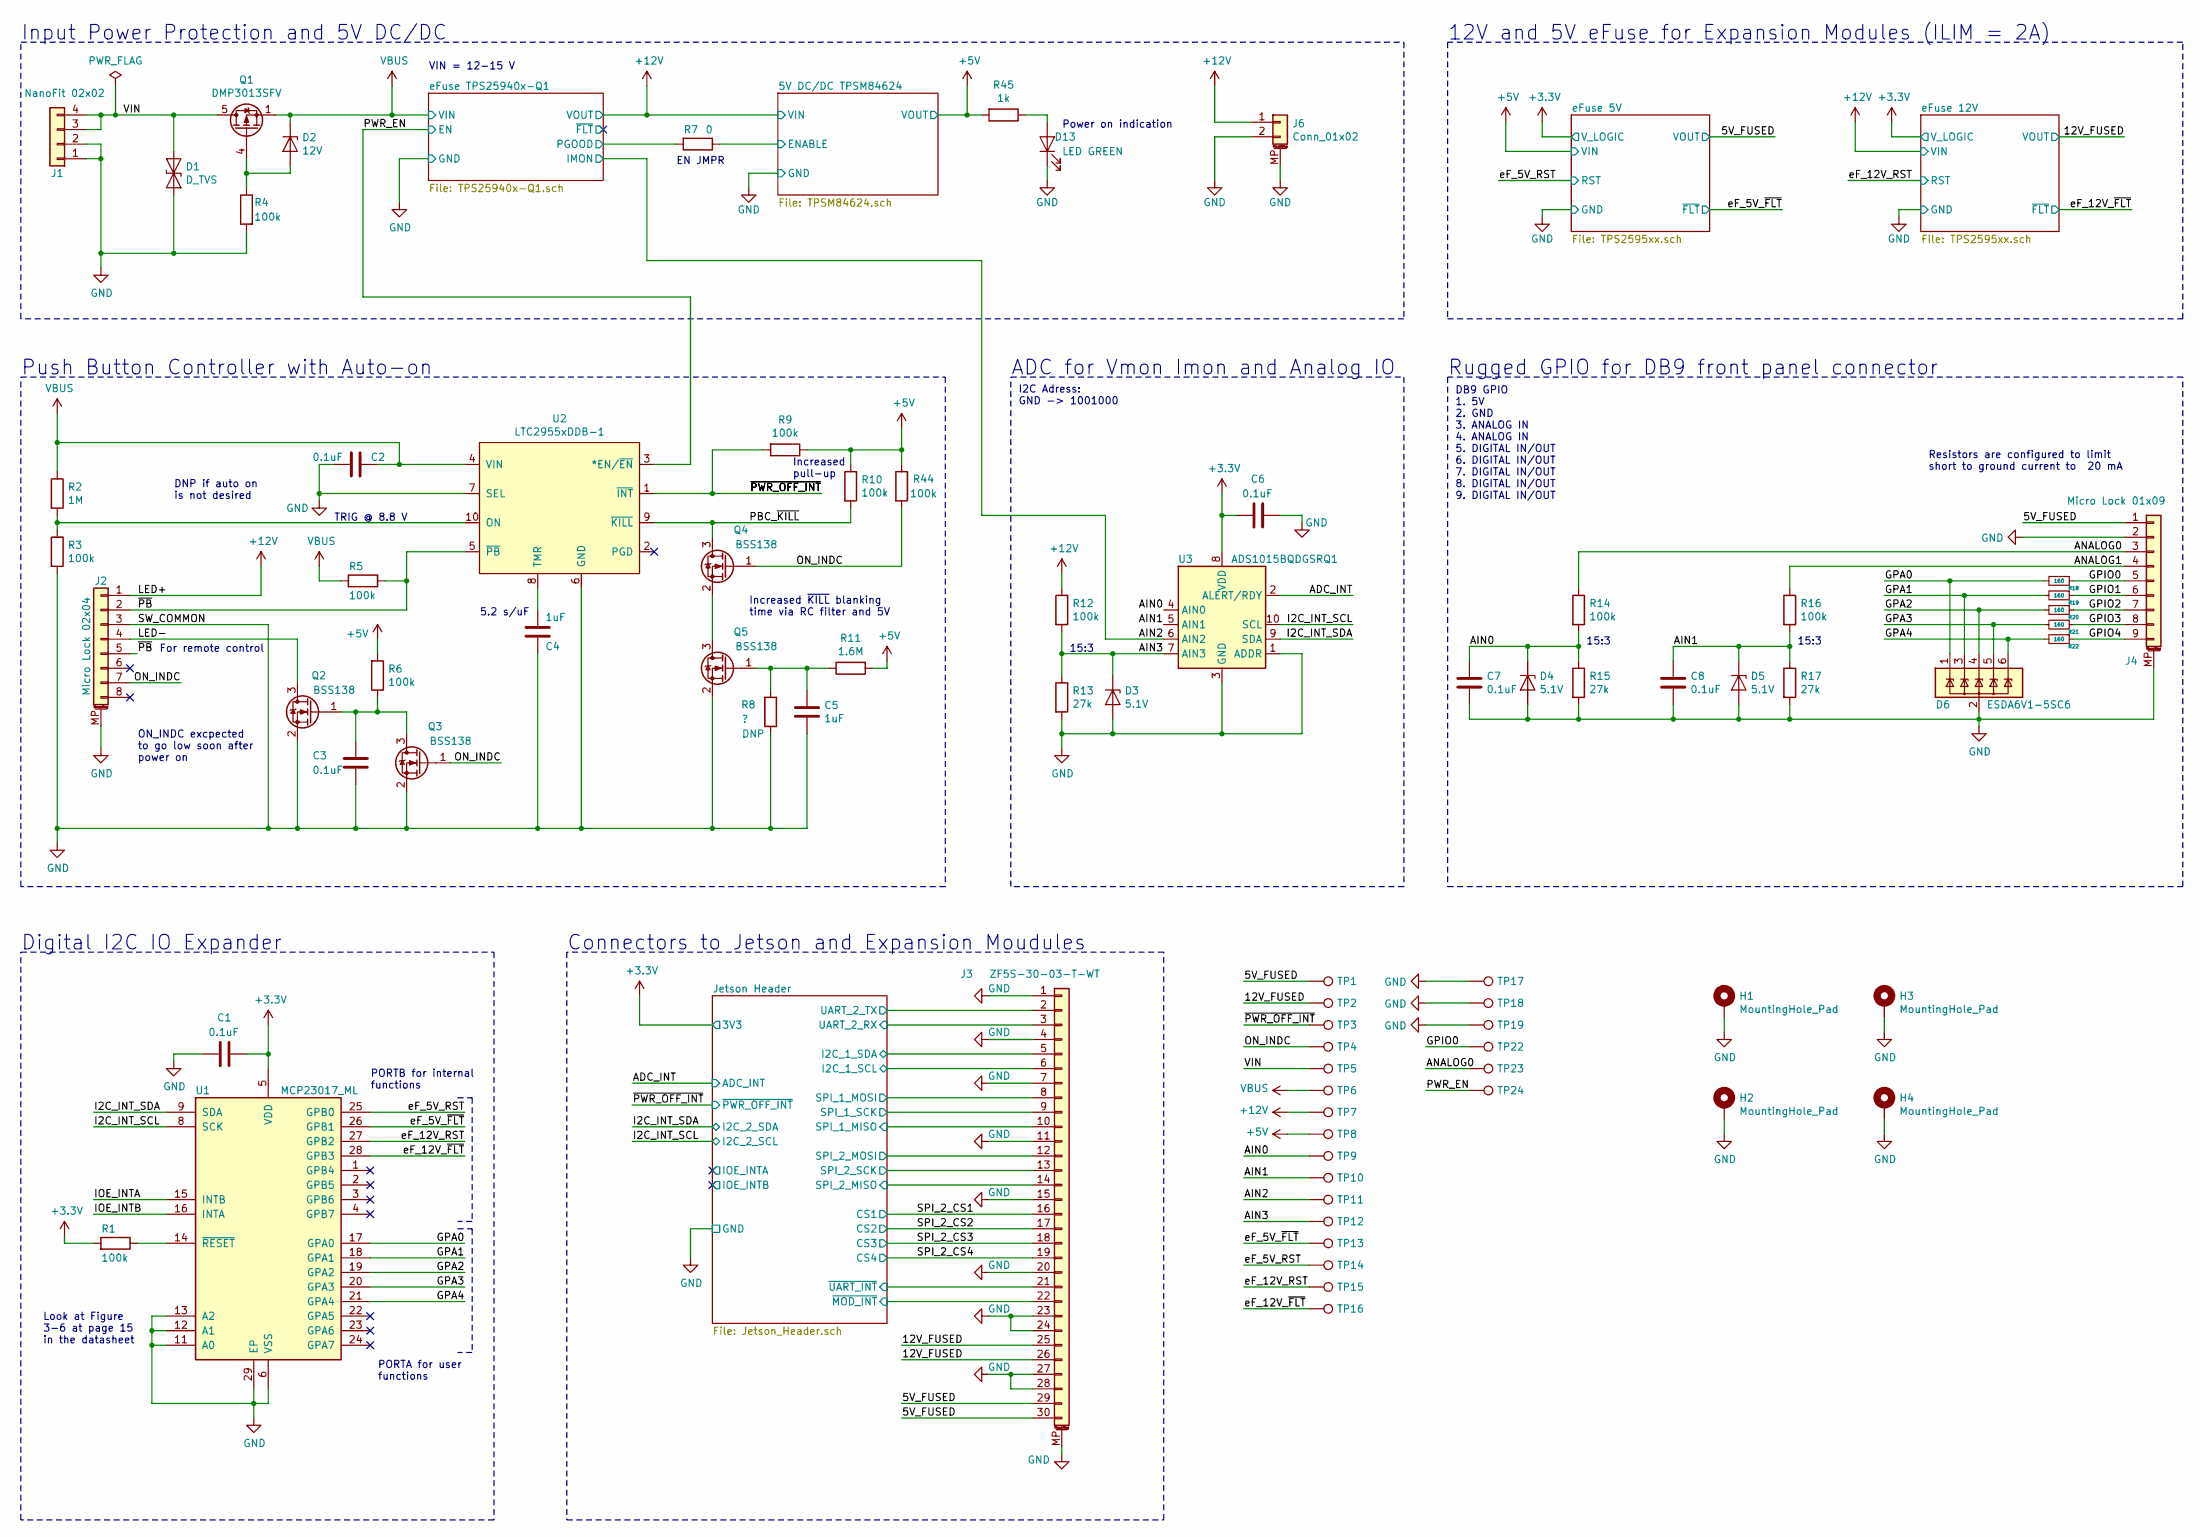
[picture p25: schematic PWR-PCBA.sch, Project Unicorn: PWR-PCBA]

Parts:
C1, C2, C3, C6, C7, C8: 0.1uF; C_0603_1608Metric
C4, C5: 1uF; C_0603_1608Metric
D1: D_TVS; D_SMB; MPN TPSMB20CA
D2: 12V; D_SOD-123; MPN MMSZ5242B-G3-08
D3, D4, D5: 5.1V; D_SOD-123; MPN MMSZ5232B-7-F
D6: ESDA6V1-5SC6; SOT-23-6; MPN ESDA6V1-5SC6
D13: LED GREEN; LED_0603_1608Metric
H1, H2, H3, H4: MountingHole_Pad; MountingHole_2.7mm_M2.5_Pad_Via
J1: NanoFit 02x02; 02x02_vertical_105310-1204; MPN 105310-1204
J2: Micro Lock 02x04; Molex_Micro-Lock_5054330871_2x4_P1.25_Vertical; MPN 5054330871
J3: ZF5S-30-03-T-WT; MPN ZF5S-30-03-T-WT-TR
J4: Micro Lock 01x09; 01x09_vertical_2059570971; MPN 205957-0971
J6: Conn_01x02; Molex_Micro-Lock_5055680271_1x02_P1.25_Vertical
Q1: DMP3013SFV; Diodes_PowerDI3333-8; MPN DMP3013SFV-7
Q2, Q3, Q4, Q5: BSS138; SOT-23
R1, R3, R4, R5, R6, R9, R10, R12, R14, R16, R44: 100k; R_0603_1608Metric
R2: 1M; R_0603_1608Metric
R7: 0; R_0603_1608Metric
R8: ?; R_0603_1608Metric
R11: 1.6M; R_0603_1608Metric
R13, R15, R17: 27k; R_0603_1608Metric
R18, R19, R20, R21, R22: 160; R_0603_1608Metric
R45: 1k; R_0603_1608Metric
TP1, TP2, TP3, TP4, TP5, TP6, TP7, TP8, TP9, TP10, TP11, TP12, TP13, TP14, TP15, TP16, TP17, TP18, TP19, TP22, TP23, TP24: TestPoint; TestPoint_THTPad_D1.0mm_Drill0.5mm
U1: MCP23017_ML; QFN-28-1EP_6x6mm_P0.65mm_EP4.25x4.25mm; MPN MCP23017-E/ML
U2: LTC2955xDDB-1; DFN-10-1EP_2x3mm_P0.5mm_EP0.64x2.4mm; MPN LTC2955IDDB-1#TRMPBF
U3: ADS1015BQDGSRQ1; TSSOP-10_3x3mm_P0.5mm; MPN ADS1015BQDGSRQ1

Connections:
+3V3: C1.2, C6.1, R1.2, U1.5 (VDD), U3.8 (VDD); also elsewhere on the board
+5V: R6.2, R9.1, R10.1, R11.2, R44.1, R45.2, TP8.1; also elsewhere on the board
+12V: J2.1, J6.1, R12.1, TP7.1; also elsewhere on the board
/5V DC/DC TPSM84624 /ENABLE: R7.1; also elsewhere on the board
/5V_FUSED: J3.29, J3.30, J4.1, TP1.1; also elsewhere on the board
/12V_FUSED: J3.25, J3.26, TP2.1; also elsewhere on the board
/ADC_INT: U3.2 (ALERT/RDY); also elsewhere on the board
/AIN0: C7.1, D4.1 (K), R14.2, R15.1, TP9.1, U3.4 (AIN0)
/AIN1: C8.1, D5.1 (K), R16.2, R17.1, TP10.1, U3.5 (AIN1)
/AIN2: TP11.1, U3.6 (AIN2); also elsewhere on the board
/AIN3: D3.1 (K), R12.2, R13.1, TP12.1, U3.7 (AIN3)
/ANALOG0: J4.3, R14.1, TP23.1
/ANALOG1: J4.4, R16.1
/GPA0: D6.1 (IO1), R18.2, U1.17 (GPA0)
/GPA1: D6.3 (IO2), R19.2, U1.18 (GPA1)
/GPA2: D6.4 (IO3), R20.2, U1.19 (GPA2)
/GPA3: D6.5 (IO4), R21.2, U1.20 (GPA3)
/GPA4: D6.6 (IO5), R22.2, U1.21 (GPA4)
/GPIO0: J4.5, R18.1, TP22.1
/GPIO1: J4.6, R19.1
/GPIO2: J4.7, R20.1
/GPIO3: J4.8, R21.1
/GPIO4: J4.9, R22.1
/I2C_INT_SCL: U1.8 (SCK), U3.10 (SCL); also elsewhere on the board
/I2C_INT_SDA: U1.9 (SDA), U3.9 (SDA); also elsewhere on the board
/IOE_INTA: U1.15 (INTB)
/IOE_INTB: U1.16 (INTA)
/Jetson Header/I2C_1_SCL: J3.6; also elsewhere on the board
/Jetson Header/I2C_1_SDA: J3.5; also elsewhere on the board
/Jetson Header/SPI_1_MISO: J3.10; also elsewhere on the board
/Jetson Header/SPI_1_MOSI: J3.8; also elsewhere on the board
/Jetson Header/SPI_1_SCK: J3.9; also elsewhere on the board
/Jetson Header/SPI_2_MISO: J3.14; also elsewhere on the board
/Jetson Header/SPI_2_MOSI: J3.12; also elsewhere on the board
/Jetson Header/SPI_2_SCK: J3.13; also elsewhere on the board
/Jetson Header/UART_2_RX: J3.3; also elsewhere on the board
/Jetson Header/UART_2_TX: J3.2; also elsewhere on the board
/Jetson Header/~MOD_INT: J3.22; also elsewhere on the board
/Jetson Header/~UART_INT: J3.21; also elsewhere on the board
/LED-: J2.4, Q2.3 (D)
/ON_INDC: J2.7, Q3.1 (G), Q4.1 (G), R44.2, TP4.1
/PBC_~KILL: Q4.3 (D), R10.2, U2.9 (~KILL)
/PWR_EN: TP24.1, U2.3 (*EN/~EN); also elsewhere on the board
/SPI_2_CS1: J3.16; also elsewhere on the board
/SPI_2_CS2: J3.17; also elsewhere on the board
/SPI_2_CS3: J3.18; also elsewhere on the board
/SPI_2_CS4: J3.19; also elsewhere on the board
/VIN: D1.2 (A2), J1.3, J1.4, Q1.5 (D), TP5.1
/eF_5V_RST: TP14.1, U1.25 (GPB0); also elsewhere on the board
/eF_5V_~FLT: TP13.1, U1.26 (GPB1); also elsewhere on the board
/eF_12V_RST: TP15.1, U1.27 (GPB2); also elsewhere on the board
/eF_12V_~FLT: TP16.1, U1.28 (GPB3); also elsewhere on the board
/eFuse TPS25940x-Q1/PGOOD: R7.2; also elsewhere on the board
/~PB: J2.2, J2.5, R5.1, U2.5 (~PB)
/~PWR_OFF_INT: R9.2, TP3.1, U2.1 (~INT); also elsewhere on the board
GND: C1.1, C2.2, C3.2, C4.2, C5.2, C6.2, C7.2, C8.2, D1.1 (A1), D3.2 (A), D4.2 (A), D5.2 (A), D6.2 (GND), D13.1 (K), H1.1, H2.1, H3.1, H4.1, J1.1, J1.2, J2.3, J2.MP (MountPin), J3.1, J3.4, J3.7, J3.11, J3.15, J3.20, J3.23, J3.24, J3.27, J3.28, J3.MP (MountPin), J4.2, J4.MP (MountPin), J6.2, J6.MP (MountPin), Q2.2 (S), Q3.2 (S), Q5.2 (S), R3.2, R4.2, R8.1, R13.2, R15.2, R17.2, TP17.1, TP18.1, TP19.1, U1.6 (VSS), U1.11 (A0), U1.12 (A1), U1.13 (A2), U1.29 (EP), U2.6 (GND), U2.7 (SEL), U3.1 (ADDR), U3.3 (GND); also elsewhere on the board
unnamed: C3.1, Q2.1 (G), Q3.3 (D), R6.1
unnamed: C4.1, U2.8 (TMR)
unnamed: C5.1, Q5.1 (G), R8.2, R11.1
unnamed: D2.2 (A), Q1.4 (G), R4.1
unnamed: D13.2 (A), R45.1
unnamed: Q4.2 (S), Q5.3 (D)
unnamed: R1.1, U1.14 (~RESET~)
unnamed: R2.2, R3.1, U2.10 (ON)
VBUS: C2.1, D2.1 (K), Q1.1 (S), Q1.2 (S), Q1.3 (S), R2.1, R5.2, TP6.1, U2.4 (VIN); also elsewhere on the board

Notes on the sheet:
VIN = 12-15 V
DNP if auto on is not desired
5.2 s/uF
TRIG @ 8.8 V
I2C Adress: GND -> 1001000
15:3
Push Button Controller with Auto-on
ADC for Vmon Imon and Analog IO
DB9 GPIO 1. 5V 2. GND 3. ANALOG IN 4. ANALOG IN 5. DIGITAL IN/OUT 6. DIGITAL IN/OUT 7. DIGITAL IN/OUT 8. DIGITAL IN/OUT 9. DIGITAL IN/OUT
EN JMPR
Increased ~KILL~ blanking time via RC filter and 5V
Increased pull-up
Rugged GPIO for DB9 front panel connector
Resistors are configured to limit short to ground current to 20 mA
Look at Figure 3-6 at page 15 in the datasheet
PORTA for user functions
PORTB for internal functions
Input Power Protection and 5V DC/DC
12V and 5V eFuse for Expansion Modules (ILIM = 2A)
Digital I2C IO Expander
Connectors to Jetson and Expansion Moudules
For remote control
Power on indication
ON_INDC excpected to go low soon after power on

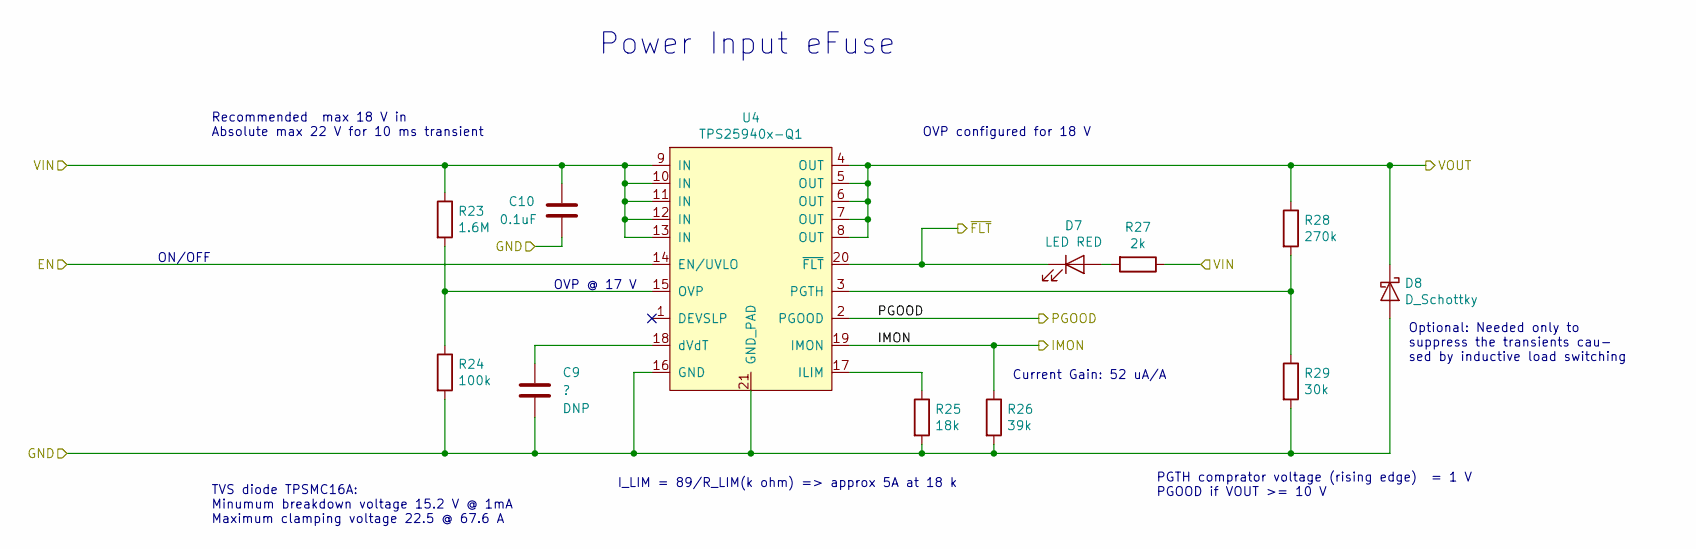
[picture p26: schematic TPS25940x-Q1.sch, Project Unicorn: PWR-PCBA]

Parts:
C9: ?; C_0603_1608Metric
C10: 0.1uF; C_0603_1608Metric
D7: LED RED; LED_0603_1608Metric
D8: D_Schottky; D_SOD-123; MPN 1N5819HW
R23: 1.6M; R_0603_1608Metric
R24: 100k; R_0603_1608Metric
R25: 18k; R_0603_1608Metric
R26: 39k; R_0603_1608Metric
R27: 2k; R_0603_1608Metric
R28: 270k; R_0603_1608Metric
R29: 30k; R_0603_1608Metric
U4: TPS25940x-Q1; QFN-20-1EP_3x4mm_P0.5mm_EP1.65x2.65mm_ThermalVias; MPN TPS25940LQRVCRQ1

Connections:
+12V: D8.1 (K), R28.1, U4.4 (OUT), U4.5 (OUT), U4.6 (OUT), U4.7 (OUT), U4.8 (OUT); also elsewhere on the board
/AIN2: R26.1, U4.19 (IMON); also elsewhere on the board
/PWR_EN: U4.14 (EN/UVLO); also elsewhere on the board
/eFuse TPS25940x-Q1/PGOOD: U4.2 (PGOOD); also elsewhere on the board
/eFuse TPS25940x-Q1/~FLT: D7.1 (K), U4.20 (~FLT)
GND: C9.2, C10.2, D8.2 (A), R24.2, R25.2, R26.2, R29.2, U4.16 (GND), U4.21 (GND_PAD); also elsewhere on the board
unnamed: C9.1, U4.18 (dVdT)
unnamed: D7.2 (A), R27.2
unnamed: R23.2, R24.1, U4.15 (OVP)
unnamed: R25.1, U4.17 (ILIM)
unnamed: R28.2, R29.1, U4.3 (PGTH)
VBUS: C10.1, R23.1, R27.1, U4.9 (IN), U4.10 (IN), U4.11 (IN), U4.12 (IN), U4.13 (IN); also elsewhere on the board

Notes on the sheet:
ON/OFF
Power Input eFuse
Recommended max 18 V in Absolute max 22 V for 10 ms transient
I_LIM = 89/R_LIM(k ohm) => approx 5A at 18 k
PGTH comprator voltage (rising edge) = 1 V PGOOD if VOUT >= 10 V
OVP configured for 18 V
Optional: Needed only to suppress the transients cau- sed by inductive load switching
TVS diode TPSMC16A: Minumum breakdown voltage 15.2 V @ 1mA Maximum clamping voltage 22.5 @ 67.6 A
OVP @ 17 V
Current Gain: 52 uA/A

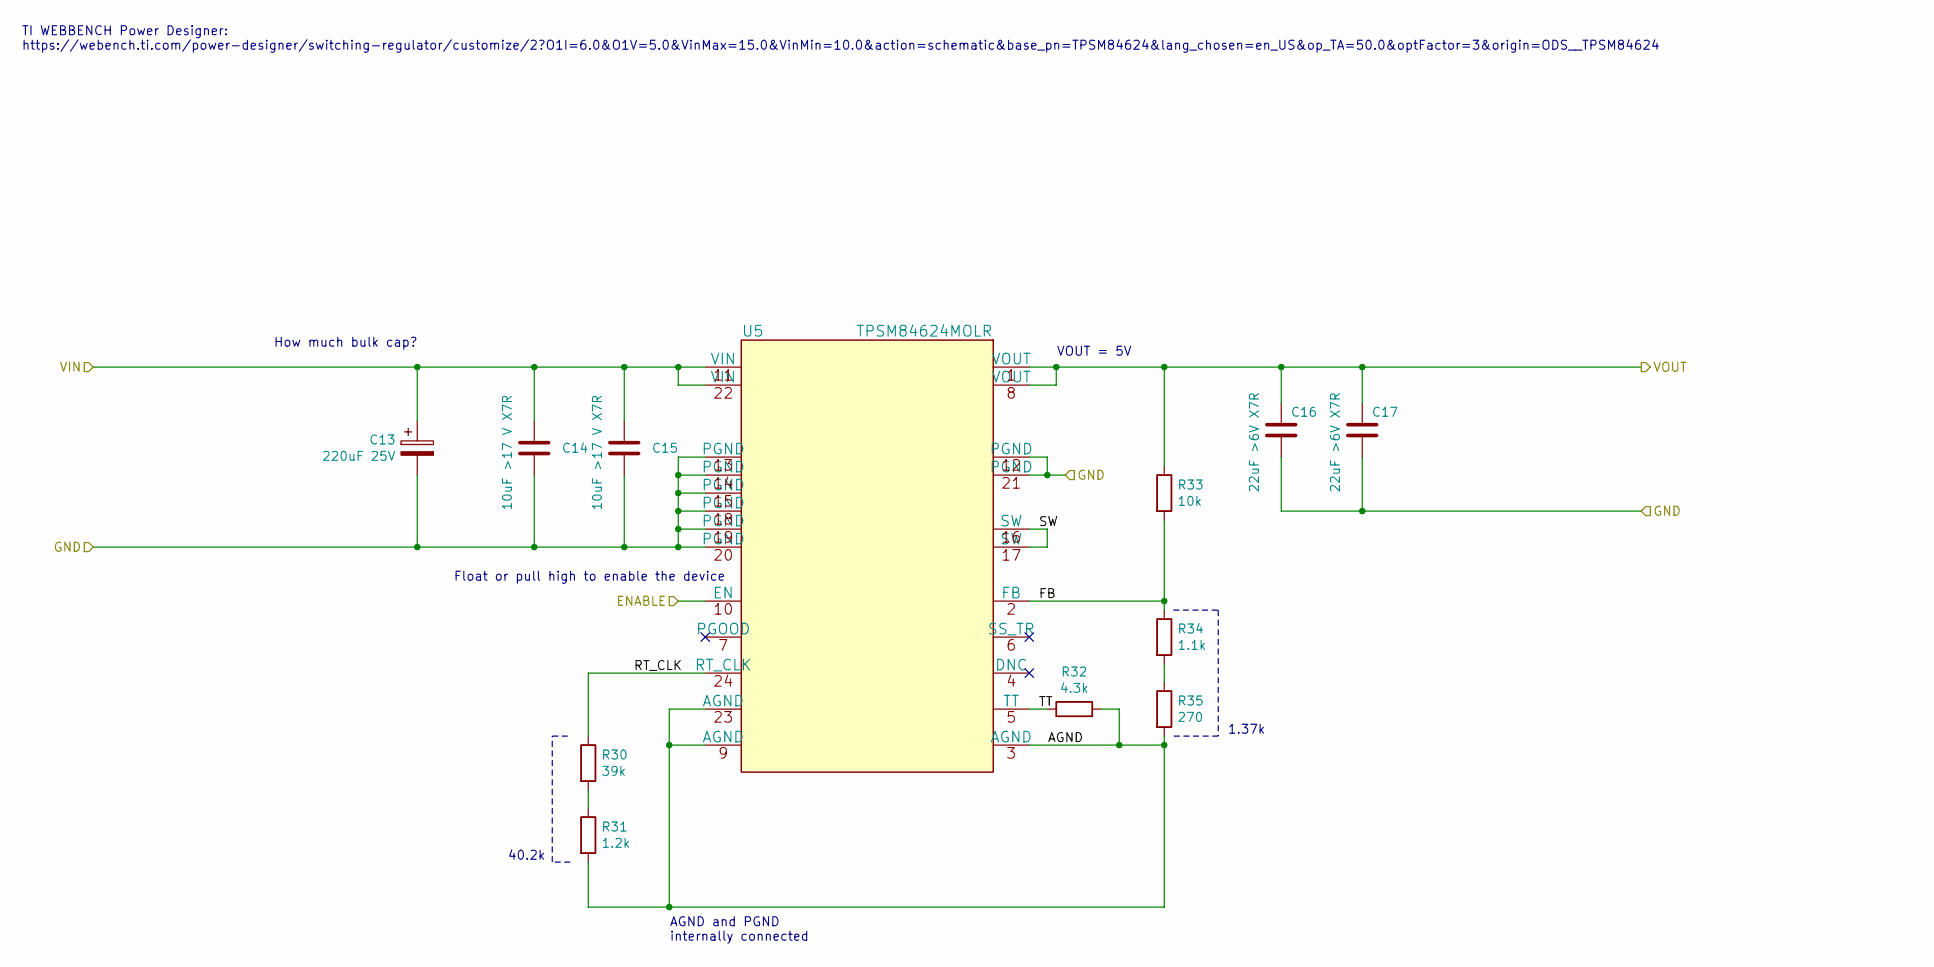
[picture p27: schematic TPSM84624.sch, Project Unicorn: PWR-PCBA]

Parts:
C13: 220uF 25V; CP_Radial_D8.0mm_P3.50mm; MPN ESE227M025AG3AA
C14, C15: 10uF >17 V X7R; C_0805_2012Metric; MPN TMK212BBJ106MG-T
C16, C17: 22uF >6V X7R; C_0805_2012Metric; MPN C0805C226M9PACTU
R30: 39k; R_0603_1608Metric
R31: 1.2k; R_0603_1608Metric
R32: 4.3k; R_0603_1608Metric
R33: 10k; R_0603_1608Metric
R34: 1.1k; R_0603_1608Metric
R35: 270; R_0603_1608Metric
U5: TPSM84624MOLR; MPN TPSM84624MOLR

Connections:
+5V: C16.1, C17.1, R33.1, U5.1 (VOUT), U5.8 (VOUT); also elsewhere on the board
+12V: C13.1, C14.1, C15.1, U5.11 (VIN), U5.22 (VIN); also elsewhere on the board
/5V DC/DC TPSM84624 /AGND: R31.2, R32.2, R35.2, U5.3 (AGND), U5.9 (AGND), U5.23 (AGND)
/5V DC/DC TPSM84624 /ENABLE: U5.10 (EN); also elsewhere on the board
/5V DC/DC TPSM84624 /FB: R33.2, R34.1, U5.2 (FB)
/5V DC/DC TPSM84624 /RT_CLK: R30.1, U5.24 (RT_CLK)
/5V DC/DC TPSM84624 /SW: U5.16 (SW), U5.17 (SW)
/5V DC/DC TPSM84624 /TT: R32.1, U5.5 (TT)
GND: C13.2, C14.2, C15.2, C16.2, C17.2, U5.12 (PGND), U5.13 (PGND), U5.14 (PGND), U5.15 (PGND), U5.18 (PGND), U5.19 (PGND), U5.20 (PGND), U5.21 (PGND); also elsewhere on the board
unnamed: R30.2, R31.1
unnamed: R34.2, R35.1

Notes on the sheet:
TI WEBBENCH Power Designer: https://webench.ti.com/power-designer/switching-regulator/customize/2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
1.37k
VOUT = 5V
AGND and PGND internally connected
40.2k
How much bulk cap?
Float or pull high to enable the device

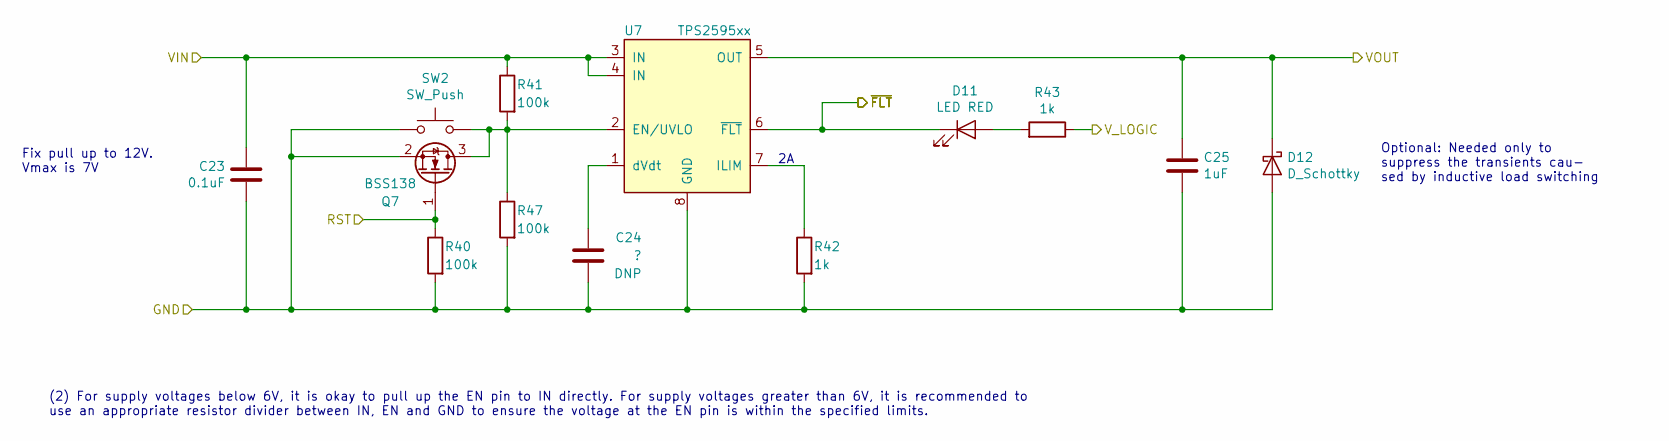
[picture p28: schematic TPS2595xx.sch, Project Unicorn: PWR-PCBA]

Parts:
C23: 0.1uF; C_0603_1608Metric
C24: ?; C_0603_1608Metric
C25: 1uF; C_0603_1608Metric
D11: LED RED; LED_0603_1608Metric
D12: D_Schottky; D_SOD-123; MPN 1N5819HW
Q7: BSS138; SOT-23
R40, R41, R47: 100k; R_0603_1608Metric
R42, R43: 1k; R_0603_1608Metric
SW2: SW_Push; KMR621NGLFS; MPN KMR621NGLFS
U7: TPS2595xx; WSON-8-1EP_2x2mm_P0.5mm_EP0.9x1.6mm_ThermalVias; MPN TPS259570DSGR

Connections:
+3V3: R43.1; also elsewhere on the board
+12V: C23.1, R41.1, U7.3 (IN), U7.4 (IN); also elsewhere on the board
/12V_FUSED: C25.1, D12.1 (K), U7.5 (OUT); also elsewhere on the board
/eF_12V_RST: Q7.1 (G), R40.1; also elsewhere on the board
/eF_12V_~FLT: D11.1 (K), U7.6 (~FLT); also elsewhere on the board
GND: C23.2, C24.2, C25.2, D12.2 (A), Q7.2 (S), R40.2, R42.2, R47.2, SW2.1, U7.8 (GND); also elsewhere on the board
unnamed: C24.1, U7.1 (dVdt)
unnamed: D11.2 (A), R43.2
unnamed: Q7.3 (D), R41.2, R47.1, SW2.2, U7.2 (EN/UVLO)
unnamed: R42.1, U7.7 (ILIM)

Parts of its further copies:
C18: 0.1uF; C_0603_1608Metric
C19: ?; C_0603_1608Metric
C20: 1uF; C_0603_1608Metric
D9: LED RED; LED_0603_1608Metric
D10: D_Schottky; D_SOD-123; MPN 1N5819HW
Q6: BSS138; SOT-23
R36, R37, R46: 100k; R_0603_1608Metric
R38, R39: 1k; R_0603_1608Metric
SW1: SW_Push; KMR621NGLFS; MPN KMR621NGLFS
U6: TPS2595xx; WSON-8-1EP_2x2mm_P0.5mm_EP0.9x1.6mm_ThermalVias; MPN TPS259570DSGR

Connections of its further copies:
+3V3: R39.1; also elsewhere on the board
+5V: C18.1, R37.1, U6.3 (IN), U6.4 (IN); also elsewhere on the board
/5V_FUSED: C20.1, D10.1 (K), U6.5 (OUT); also elsewhere on the board
/eF_5V_RST: Q6.1 (G), R36.1; also elsewhere on the board
/eF_5V_~FLT: D9.1 (K), U6.6 (~FLT); also elsewhere on the board
GND: C18.2, C19.2, C20.2, D10.2 (A), Q6.2 (S), R36.2, R38.2, R46.2, SW1.1, U6.8 (GND); also elsewhere on the board
unnamed: C19.1, U6.1 (dVdt)
unnamed: D9.2 (A), R39.2
unnamed: Q6.3 (D), R37.2, R46.1, SW1.2, U6.2 (EN/UVLO)
unnamed: R38.1, U6.7 (ILIM)

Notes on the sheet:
Optional: Needed only to suppress the transients cau- sed by inductive load switching
Fix pull up to 12V. Vmax is 7V
(2) For supply voltages below 6V, it is okay to pull up the EN pin to IN directly. For supply voltages greater than 6V, it is recommended to use an appropriate resistor divider between IN, EN and GND to ensure the voltage at the EN pin is within the specified limits.

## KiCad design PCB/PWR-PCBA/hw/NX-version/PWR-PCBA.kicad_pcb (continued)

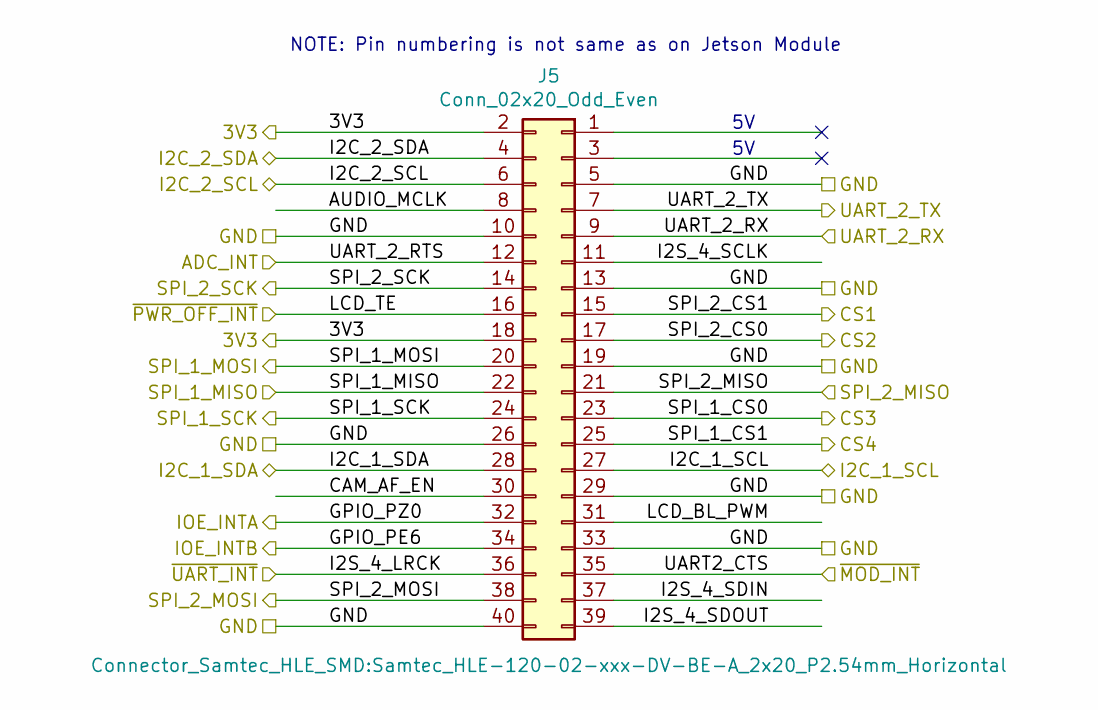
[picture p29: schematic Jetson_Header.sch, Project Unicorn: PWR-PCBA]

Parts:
J5: Conn_02x20_Odd_Even; Samtec_HLE-120-02-xxx-DV-BE-A_2x20_P2.54mm_Horizontal; MPN HLE-120-02-F-DV-BE-A

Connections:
+3V3: J5.2, J5.18; also elsewhere on the board
/ADC_INT: J5.12; also elsewhere on the board
/I2C_INT_SCL: J5.6; also elsewhere on the board
/I2C_INT_SDA: J5.4; also elsewhere on the board
/Jetson Header/AUDIO_MCLK: J5.8
/Jetson Header/CAM_AF_EN: J5.30
/Jetson Header/I2C_1_SCL: J5.27; also elsewhere on the board
/Jetson Header/I2C_1_SDA: J5.28; also elsewhere on the board
/Jetson Header/I2S_4_SCLK: J5.11
/Jetson Header/I2S_4_SDIN: J5.37
/Jetson Header/I2S_4_SDOUT: J5.39
/Jetson Header/IOE_INTA: J5.32
/Jetson Header/IOE_INTB: J5.34
/Jetson Header/LCD_BL_PWM: J5.31
/Jetson Header/SPI_1_MISO: J5.22; also elsewhere on the board
/Jetson Header/SPI_1_MOSI: J5.20; also elsewhere on the board
/Jetson Header/SPI_1_SCK: J5.24; also elsewhere on the board
/Jetson Header/SPI_2_MISO: J5.21; also elsewhere on the board
/Jetson Header/SPI_2_MOSI: J5.38; also elsewhere on the board
/Jetson Header/SPI_2_SCK: J5.14; also elsewhere on the board
/Jetson Header/UART_2_RX: J5.9; also elsewhere on the board
/Jetson Header/UART_2_TX: J5.7; also elsewhere on the board
/Jetson Header/~MOD_INT: J5.35; also elsewhere on the board
/Jetson Header/~UART_INT: J5.36; also elsewhere on the board
/SPI_2_CS1: J5.15; also elsewhere on the board
/SPI_2_CS2: J5.17; also elsewhere on the board
/SPI_2_CS3: J5.23; also elsewhere on the board
/SPI_2_CS4: J5.25; also elsewhere on the board
/~PWR_OFF_INT: J5.16; also elsewhere on the board
GND: J5.5, J5.10, J5.13, J5.19, J5.26, J5.29, J5.33, J5.40; also elsewhere on the board

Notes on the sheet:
NOTE: Pin numbering is not same as on Jetson Module

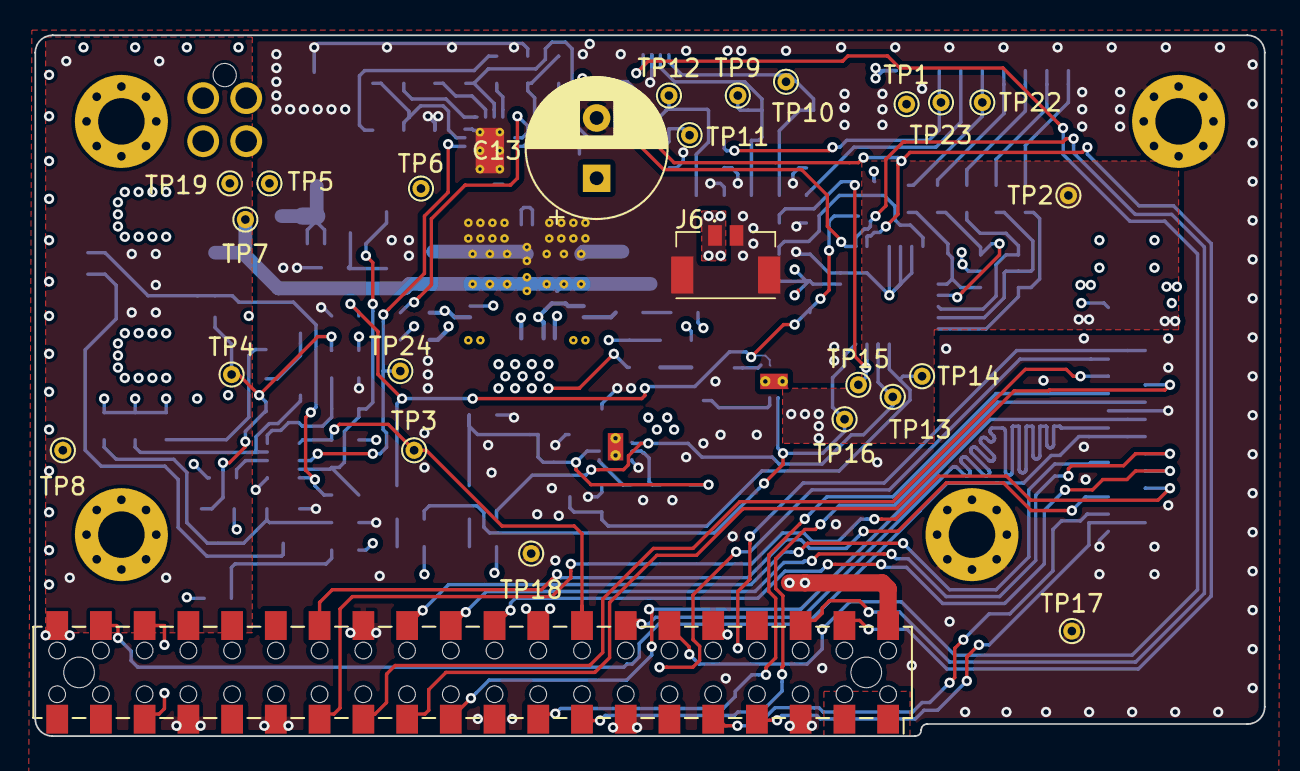
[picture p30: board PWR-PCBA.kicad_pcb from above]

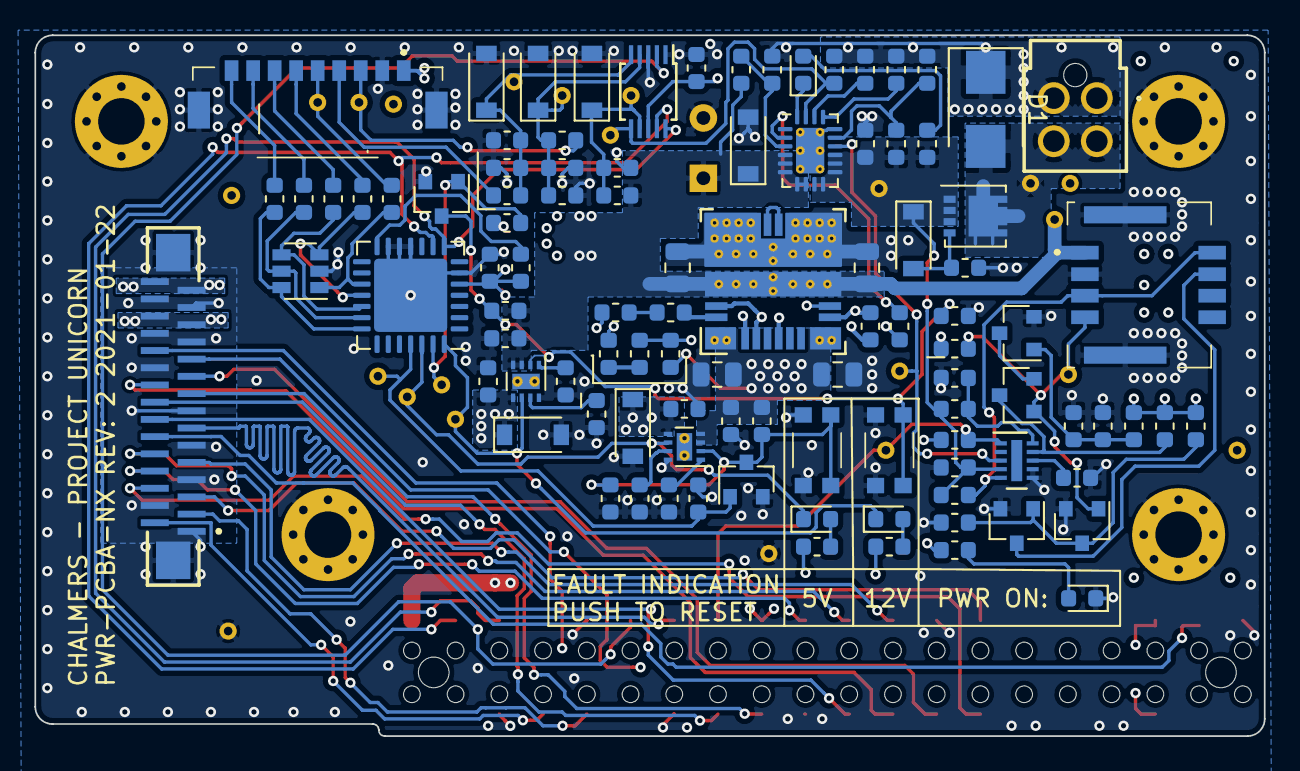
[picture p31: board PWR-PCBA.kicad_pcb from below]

Board: 4 copper layers, 71.4 x 40.7 mm, 129 parts (100 on the bottom side), 84 nets.

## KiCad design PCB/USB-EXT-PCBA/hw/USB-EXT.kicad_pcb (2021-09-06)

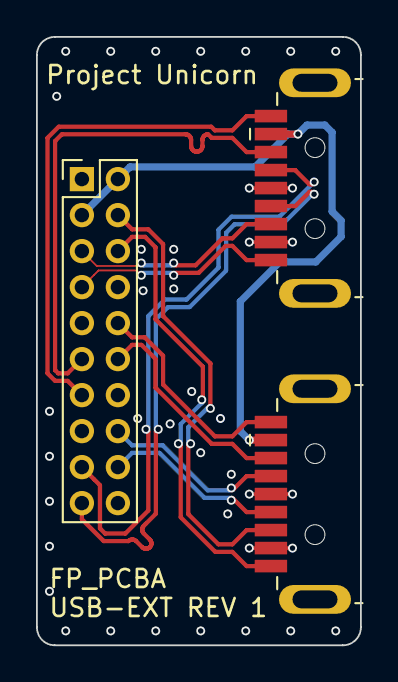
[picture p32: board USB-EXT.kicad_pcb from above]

Board: 4 copper layers, 18.0 x 33.8 mm, 3 parts (0 on the bottom side), 14 nets.

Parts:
J1: 2x USB 3.0 Header; PinHeader_2x10_P2.00mm_Vertical
J2, J3: USB3_A; USB3_A_Plug_AMPHENOL_GSB316441CEU

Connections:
/IntA_P1_D+: J1.18, J2.3
/IntA_P1_D-: J1.16, J2.2
/IntA_P1_SSRX+: J1.6, J2.5
/IntA_P1_SSRX-: J1.4, J2.6
/IntA_P1_SSTX+: J1.12, J2.8
/IntA_P1_SSTX-: J1.10, J2.9
/IntA_P2_D+: J1.19, J3.3
/IntA_P2_D-: J1.17, J3.2
/IntA_P2_SSRX+: J1.7, J3.5
/IntA_P2_SSRX-: J1.5, J3.6
/IntA_P2_SSTX+: J1.13, J3.9
/IntA_P2_SSTX-: J1.11, J3.8
GND: J1.8, J1.9, J1.14, J1.15, J2.4, J2.7, J2.10, J3.4, J3.7, J3.10
VBUS: J1.2, J1.3, J2.1, J3.1

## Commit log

2021-09-06 initial commit CAD files
    [02x02_vertical_105310-1204.iam, 1009410_3D.ipt, 1009799_3D.ipt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]
2024-02-23 added 10Gbit version, not finished
    [ABPH 1600-UT_3D.0011.ipt, ABPH 1600-UT_3D.ipt, ABPH 1600-UT_3D_MARV_Camera.0001.ipt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]
2024-02-26 10GbE connector now on front panel
    [1009799_3D_Front_10Gbit.0001.ipt, 1009799_3D_Front_10Gbit.ipt, 3D_AJP92A8813.ipt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]
2024-03-06 added new cable fastener for 10Gbit version
    [3D_AJP92A8813.stp, 963050042.ipt, Cable_Fastener_10Gbit.0007.ipt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]
2024-03-08 added CAM for front panel 10Gbit version
    [02x02_vertical_105310-1204.0001.iam, 02x02_vertical_105310-1204.iam, 1009410_3D.0003.ipt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]

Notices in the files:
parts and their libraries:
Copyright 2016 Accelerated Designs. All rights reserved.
